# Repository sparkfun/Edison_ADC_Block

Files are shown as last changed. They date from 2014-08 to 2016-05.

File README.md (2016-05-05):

SparkFun Block for Intel Edison - ADC
==================================================

SparkFun Block for Intel Edison - ADC

[*SparkFun Block for Intel Edison - ADC (DEV-13770)*](https://www.sparkfun.com/products/13770)

This card adds ADC functionality to the Edison's I<sup>2</sup>C bus. 
The ADS1015 ADC from TI provides a single 12-bit delta-sigma convertor with an analog multiplexer. 
It can be configured as a four-channel single-ended device or as a two-channel differential device.

The board has jumpers to allow selection of the I<sup>2</sup>C slave address among four different options, allowing up to four of these cards to be stacked under one Edison. 
The sampling rate is not sufficient for audio capture, at 2.2kHz, but it should be adequate for most control applications.

Repository Contents
-------------------

* **/Hardware** - Eagle design files (.brd, .sch)
* **/Production** - Production panel files (.brd)

Documentation
--------------

* **[Hookup Guide](https://learn.sparkfun.com/tutorials/sparkfun-blocks-for-intel-edison---adc-v20)** - Basic hookup guide for the Edison ADC Block.
* **[SparkFun Fritzing repo](https://github.com/sparkfun/Fritzing_Parts)** - Fritzing diagrams for SparkFun products.
* **[SparkFun 3D Model repo](https://github.com/sparkfun/3D_Models)** - 3D models of SparkFun products. 

Version History
---------------
* [v21](https://github.com/sparkfun/Edison_ADC_Block/tree/V_2.1) - Version 2.1. Currently for sale. Fixes noise on the ADC lines, adds locking header footprint. 
* [v20](https://github.com/sparkfun/Edison_ADC_Block/tree/V_2.0) - Version 2.0. Retired. 
* [v10](https://github.com/sparkfun/Edison_ADC_Block/tree/v10) - Original release. Retired.

License Information
-------------------

This product is _**open source**_! 

Please review the LICENSE.md file for license information. 

If you have any questions or concerns on licensing, please contact techsupport@sparkfun.com.

Distributed as-is; no warranty is given.

- Your friends at SparkFun.

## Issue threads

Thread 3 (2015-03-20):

Flag label needed

ericorosel, 2015-03-20:
I think it would be nice to add a flag label to the VREF net connected to the 8-pin header, purely for the ease of reading/interpretation.

Right now it does not have any visible label.

caseykuhns, 2015-03-23:
fixed

Closed 2015-03-23.

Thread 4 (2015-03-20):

Board dimension thickness

ericorosel, 2015-03-20:
Noticed that the board dimension thickness is 6mil instead of 8mil.

If this is intentional disregard.

caseykuhns, 2015-03-23:
fixed

Closed 2015-03-23.

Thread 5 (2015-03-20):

Copper Pour Isolate

ericorosel, 2015-03-20:
Currently set to 2mil instead of 12mil.

if this is intentional, disregard.

caseykuhns, 2015-03-23:
fixed

ericorosel, 2015-03-24:
Looks like the isolate got set to 1.2mil instead of 12mil

caseykuhns, 2015-04-09:
Ok, I looked at other blocks and it looks like 2mil isolate is the norm.  We have 6mill spacing set by the DRU.  The 2mil allows the GND to connect to the edison connectors, without it, it gets ugly fast.

ericorosel, 2015-04-10:
Sounds good, thanks

Closed 2015-04-10.

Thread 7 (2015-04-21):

ADC Block V20 Proto Checklist #2 Issues

ericorosel, 2015-04-21:
(1) Looks like there is a mix and match of different sized traces around the PCA (some .01" and some .006"). The .006" traces going to the Hirose are okay, but I think we could go up to .01" on some of the smaller traces that do not lead to the Hirose.

As of now I think functionality should be fine, but for consistency, it may be worth changing some of the trace sizes; up to you.

(2) Can you add a line/polygon of "Trestrict" to the side of the GND pad on the PCA to get rid of the GND hash mark on the side of the pad. (Between SDA1 and GND)

(3) The measurement graphics are on "TDocu" instead of the "Measures" layer; up to you.

caseykuhns, 2015-04-26:
1) I fixed all trace widths to be .01" the .06 are connecting the hirose connectors
2) added the T restrict
3) Moved dimensions to Measures layer.

Closed 2015-04-26.

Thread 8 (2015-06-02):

Check the silk I added

mhord, 2015-06-02:
I removed the per-pin silk and added a table with the pertinent differential pin information. Check it and see if it matches expectations.

mhord, 2015-06-02:
Note that I didn't put it on both sides, however, so if editing it, please put a copy on the back once you're done!

Closed 2016-07-19.

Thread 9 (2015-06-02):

Regulator stability

mhord, 2015-06-02:
The 3.3V reference rail is bouncing all over the place, the same thing we saw with the FreeSoC2.

I tried a 2.2uF cap on there, as we've got on the FreeSoC, but no luck.

Probably going to have to find a higher ESR small package tant for this. Also, going to need another proto round to verify it.

Closed 2016-07-19.

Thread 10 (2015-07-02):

V20 Checklist Issues

ericorosel, 2015-07-02:
Got an air wire on the HIROSE connectors (top and bottom), looks like the GND pour doesn't want to make a connection. Upper right of the connector

caseykuhns, 2015-07-20:
should be good now, take a look

Closed 2015-07-20.

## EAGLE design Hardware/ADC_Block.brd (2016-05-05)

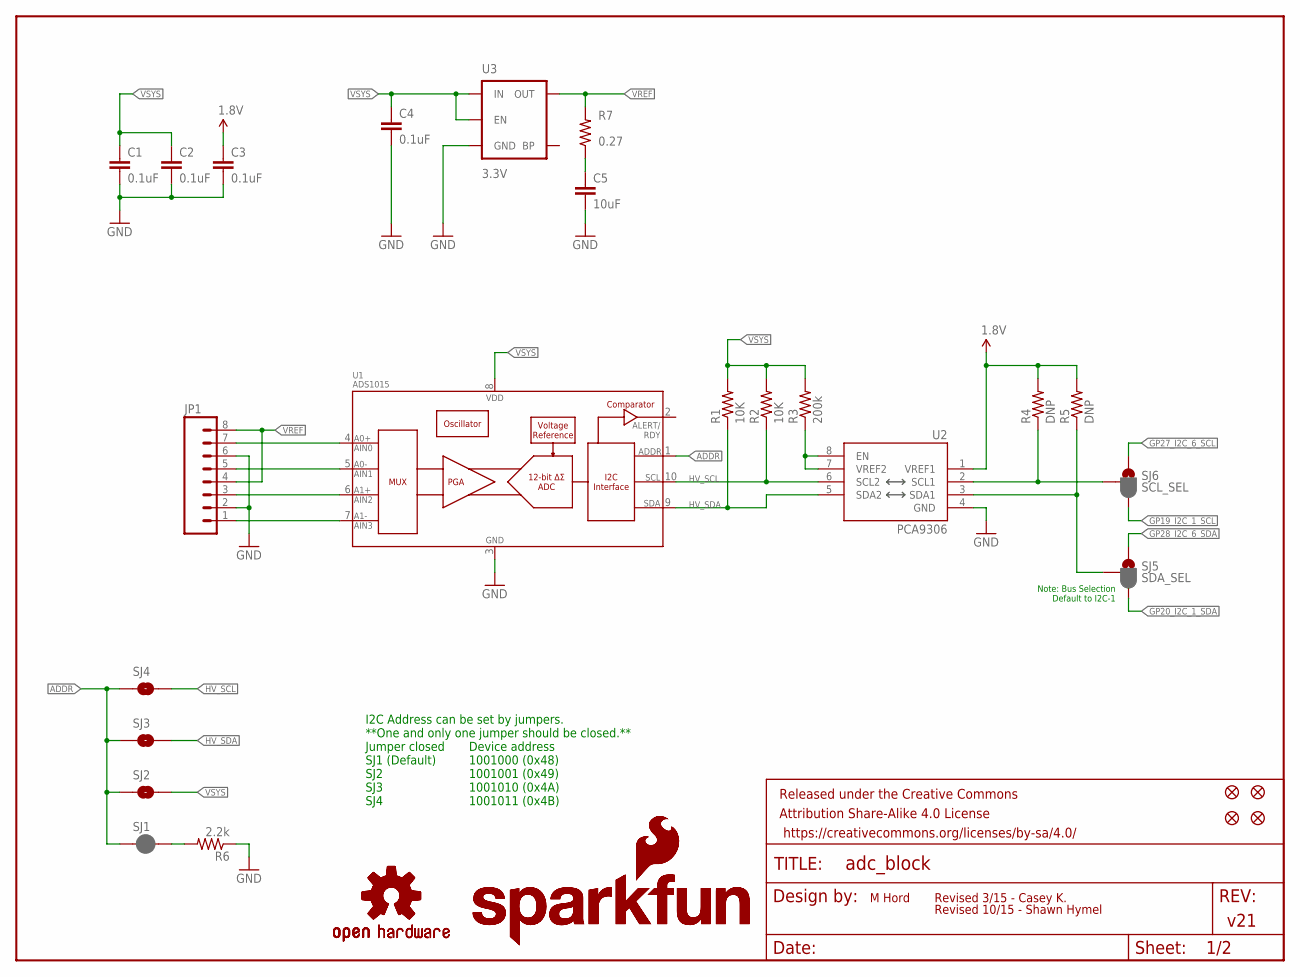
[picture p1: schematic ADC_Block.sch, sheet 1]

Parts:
C1, C2, C3, C4: 0.1uF; 0603-CAP
C5: 10uF; 0805-CAP
FID1, FID2, FID3, FID4: FIDUCIAL1X2; FIDUCIAL-1X2
FRAME1: FRAME-LETTER; CREATIVE_COMMONS
JP1: M08LOCK; 1X08_LOCK
LOGO1, LOGO3: SFE_LOGO_NAME_FLAME.1_INCH; SFE_LOGO_NAME_FLAME_.1
LOGO2, LOGO4: OSHW-LOGOS; OSHW-LOGO-S
R1, R2: 10K; 0603-RES
R3: 200k; 0603-RES
R4, R5: DNP; 0603-RES
R6: 2.2k; 0603-RES
R7: 0.27; 0603-RES
SJ1: JUMPER-PAD-2-NC_BY_PASTE; PAD-JUMPER-2-NC_BY_PASTE_YES_SILK
SJ2, SJ3, SJ4: JUMPER-PAD-2-NOYES_SILK; PAD-JUMPER-2-NO_YES_SILK
SJ5: SDA_SEL; PAD-JUMPER-3-2OF3_NC_BY_PASTE_YES_SILK_FULL_BOX
SJ6: SCL_SEL; PAD-JUMPER-3-2OF3_NC_BY_PASTE_YES_SILK_FULL_BOX
U1: ADS1015; MSOP10
U2: PCA9306; PCA9306DC-1:1
U3: 3.3V; SOT23-5

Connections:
1.8V: C3.1, R4.2, R5.2, U2.1 (VREF1); also elsewhere on the board
A0+/AIN0: JP1.7, U1.4 (AIN0)
A0-/AIN1: JP1.5, U1.5 (AIN1)
A1+/AIN2: JP1.3, U1.6 (AIN2)
A1-/AIN3: JP1.1, U1.7 (AIN3)
ADDR: SJ1.1, SJ2.1, SJ3.1, SJ4.1, U1.1 (ADDR)
GND: C1.2, C2.2, C3.2, C4.2, C5.2, JP1.2, JP1.6, R6.1, U1.3 (VSS), U2.4 (GND), U3.2 (GND); also elsewhere on the board
GP19_I2C_1_SCL: SJ6.3; also elsewhere on the board
GP20_I2C_1_SDA: SJ5.3; also elsewhere on the board
GP27_I2C_6_SCL: SJ6.1; also elsewhere on the board
GP28_I2C_6_SDA: SJ5.1; also elsewhere on the board
HV_SCL: R2.1, SJ4.2, U1.10 (SCL), U2.6 (SCL2)
HV_SDA: R1.1, SJ3.2, U1.9 (SDA), U2.5 (SDA2)
unnamed: R3.1, U2.7 (VREF2), U2.8 (EN)
unnamed: R4.1, SJ6.2, U2.2 (SCL1)
unnamed: R6.2, SJ1.2
unnamed: R5.1, SJ5.2, U2.3 (SDA1)
unnamed: C5.1, R7.1
VREF: JP1.4, JP1.8, R7.2, U3.5 (OUT)
VSYS: C1.1, C2.1, C4.1, R1.2, R2.2, R3.2, SJ2.2, U1.8 (VDD), U3.1 (IN), U3.3 (EN); also elsewhere on the board

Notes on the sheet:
I2C Address can be set by jumpers. **One and only one jumper should be closed.** Jumper closed SJ1 (Default) SJ2 SJ3 SJ4
Device address 1001000 (0x48) 1001001 (0x49) 1001010 (0x4A) 1001011 (0x4B)
v21
M Hord
Revised 3/15 - Casey K.
Note: Bus Selection Default to I2C-1
Revised 10/15 - Shawn Hymel

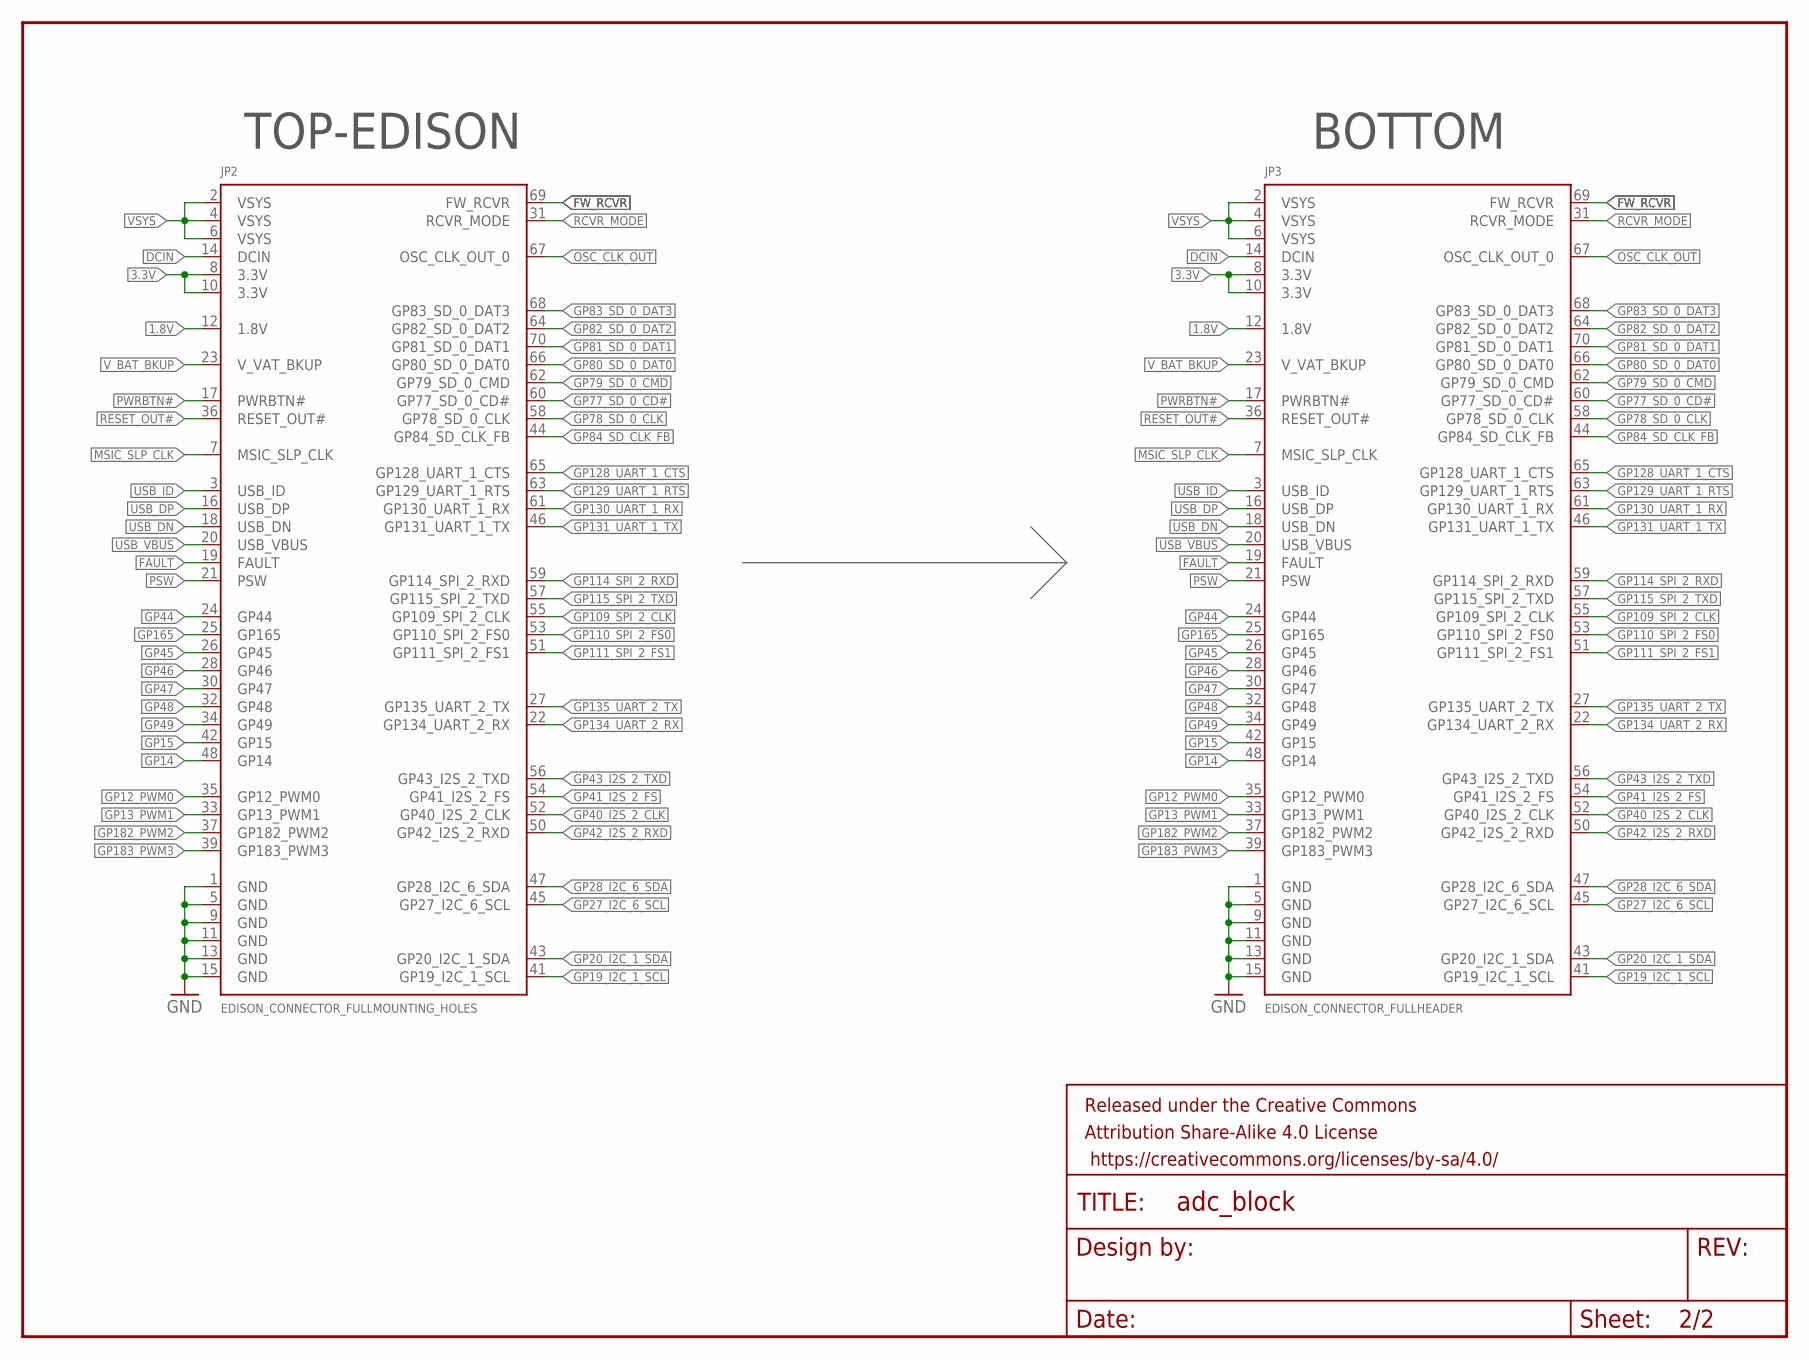
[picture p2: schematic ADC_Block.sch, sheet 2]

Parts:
FRAME2: FRAME-LETTER; CREATIVE_COMMONS
JP2: EDISON_CONNECTOR_FULLMOUNTING_HOLES; EDISON_DAUGHTER
JP3: EDISON_CONNECTOR_FULLHEADER; DF40C-70DP-0.4(51)

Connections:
1.8V: JP2.12 (1.8V), JP3.12 (1.8V); also elsewhere on the board
3.3V: JP2.8 (3.3V), JP2.10 (3.3V), JP3.8 (3.3V), JP3.10 (3.3V)
DCIN: JP2.14 (DCIN), JP3.14 (DCIN)
FAULT: JP2.19 (FAULT), JP3.19 (FAULT)
FW_RCVR: JP2.69 (FW_RCVR), JP3.69 (FW_RCVR)
GND: JP2.1 (GND), JP2.5 (GND), JP2.9 (GND), JP2.11 (GND), JP2.13 (GND), JP2.15 (GND), JP3.1 (GND), JP3.5 (GND), JP3.9 (GND), JP3.11 (GND), JP3.13 (GND), JP3.15 (GND); also elsewhere on the board
GP12_PWM0: JP2.35 (GP12_PWM0), JP3.35 (GP12_PWM0)
GP13_PWM1: JP2.33 (GP13_PWM1), JP3.33 (GP13_PWM1)
GP14: JP2.48 (GP14), JP3.48 (GP14)
GP15: JP2.42 (GP15), JP3.42 (GP15)
GP19_I2C_1_SCL: JP2.41 (GP19_I2C_1_SCL), JP3.41 (GP19_I2C_1_SCL); also elsewhere on the board
GP20_I2C_1_SDA: JP2.43 (GP20_I2C_1_SDA), JP3.43 (GP20_I2C_1_SDA); also elsewhere on the board
GP27_I2C_6_SCL: JP2.45 (GP27_I2C_6_SCL), JP3.45 (GP27_I2C_6_SCL); also elsewhere on the board
GP28_I2C_6_SDA: JP2.47 (GP28_I2C_6_SDA), JP3.47 (GP28_I2C_6_SDA); also elsewhere on the board
GP40_I2S_2_CLK: JP2.52 (GP40_I2S_2_CLK), JP3.52 (GP40_I2S_2_CLK)
GP41_I2S_2_FS: JP2.54 (GP41_I2S_2_FS), JP3.54 (GP41_I2S_2_FS)
GP42_I2S_2_RXD: JP2.50 (GP42_I2S_2_RXD), JP3.50 (GP42_I2S_2_RXD)
GP43_I2S_2_TXD: JP2.56 (GP43_I2S_2_TXD), JP3.56 (GP43_I2S_2_TXD)
GP44: JP2.24 (GP44), JP3.24 (GP44)
GP45: JP2.26 (GP45), JP3.26 (GP45)
GP46: JP2.28 (GP46), JP3.28 (GP46)
GP47: JP2.30 (GP47), JP3.30 (GP47)
GP48: JP2.32 (GP48), JP3.32 (GP48)
GP49: JP2.34 (GP49), JP3.34 (GP49)
GP77_SD_0_CD#: JP2.60 (GP77_SD_0_CD#), JP3.60 (GP77_SD_0_CD#)
GP78_SD_0_CLK: JP2.58 (GP78_SD_0_CLK), JP3.58 (GP78_SD_0_CLK)
GP79_SD_0_CMD: JP2.62 (GP79_SD_0_CMD), JP3.62 (GP79_SD_0_CMD)
GP80_SD_0_DAT0: JP2.66 (GP80_SD_0_DAT0), JP3.66 (GP80_SD_0_DAT0)
GP81_SD_0_DAT1: JP2.70 (GP81_SD_0_DAT1), JP3.70 (GP81_SD_0_DAT1)
GP82_SD_0_DAT2: JP2.64 (GP82_SD_0_DAT2), JP3.64 (GP82_SD_0_DAT2)
GP83_SD_0_DAT3: JP2.68 (GP83_SD_0_DAT3), JP3.68 (GP83_SD_0_DAT3)
GP84_SD_CLK_FB: JP2.44 (GP84_SD_CLK_FB), JP3.44 (GP84_SD_CLK_FB)
GP109_SPI_2_CLK: JP2.55 (GP109_SPI_2_CLK), JP3.55 (GP109_SPI_2_CLK)
GP110_SPI_2_FS0: JP2.53 (GP110_SPI_2_FS0), JP3.53 (GP110_SPI_2_FS0)
GP111_SPI_2_FS1: JP2.51 (GP111_SPI_2_FS1), JP3.51 (GP111_SPI_2_FS1)
GP114_SPI_2_RXD: JP2.59 (GP114_SPI_2_RXD), JP3.59 (GP114_SPI_2_RXD)
GP115_SPI_2_TXD: JP2.57 (GP115_SPI_2_TXD), JP3.57 (GP115_SPI_2_TXD)
GP128_UART_1_CTS: JP2.65 (GP128_UART_1_CTS), JP3.65 (GP128_UART_1_CTS)
GP129_UART_1_RTS: JP2.63 (GP129_UART_1_RTS), JP3.63 (GP129_UART_1_RTS)
GP130_UART_1_RX: JP2.61 (GP130_UART_1_RX), JP3.61 (GP130_UART_1_RX)
GP131_UART_1_TX: JP2.46 (GP131_UART_1_TX), JP3.46 (GP131_UART_1_TX)
GP134_UART_2_RX: JP2.22 (GP134_UART_2_RX), JP3.22 (GP134_UART_2_RX)
GP135_UART_2_TX: JP2.27 (GP135_UART_2_TX), JP3.27 (GP135_UART_2_TX)
GP165: JP2.25 (GP165), JP3.25 (GP165)
GP182_PWM2: JP2.37 (GP182_PWM2), JP3.37 (GP182_PWM2)
GP183_PWM3: JP2.39 (GP183_PWM3), JP3.39 (GP183_PWM3)
MSIC_SLP_CLK: JP2.7 (MSIC_SLP_CLK), JP3.7 (MSIC_SLP_CLK)
OSC_CLK_OUT: JP2.67 (OSC_CLK_OUT_0), JP3.67 (OSC_CLK_OUT_0)
PSW: JP2.21 (PSW), JP3.21 (PSW)
PWRBTN#: JP2.17 (PWRBTN#), JP3.17 (PWRBTN#)
RCVR_MODE: JP2.31 (RCVR_MODE), JP3.31 (RCVR_MODE)
RESET_OUT#: JP2.36 (RESET_OUT#), JP3.36 (RESET_OUT#)
USB_DN: JP2.18 (USB_DN), JP3.18 (USB_DN)
USB_DP: JP2.16 (USB_DP), JP3.16 (USB_DP)
USB_ID: JP2.3 (USB_ID), JP3.3 (USB_ID)
USB_VBUS: JP2.20 (USB_VBUS), JP3.20 (USB_VBUS)
VSYS: JP2.2 (VSYS), JP2.4 (VSYS), JP2.6 (VSYS), JP3.2 (VSYS), JP3.4 (VSYS), JP3.6 (VSYS); also elsewhere on the board
V_BAT_BKUP: JP2.23 (V_VAT_BKUP), JP3.23 (V_VAT_BKUP)

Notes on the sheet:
TOP-EDISON
BOTTOM

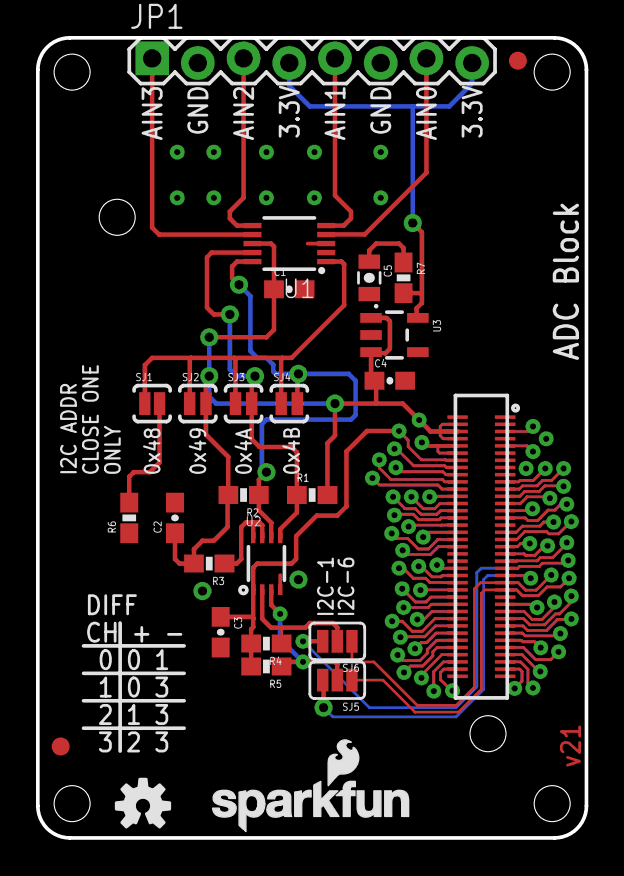
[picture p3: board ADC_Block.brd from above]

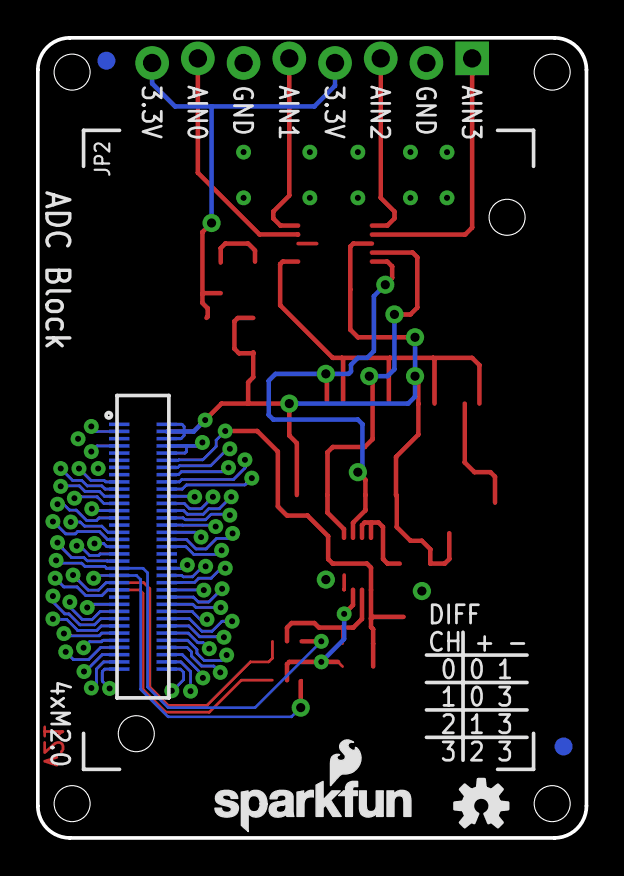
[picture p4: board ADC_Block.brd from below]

Board: 2 copper layers, 30.5 x 44.5 mm, 34 parts (6 on the bottom side), 71 nets.

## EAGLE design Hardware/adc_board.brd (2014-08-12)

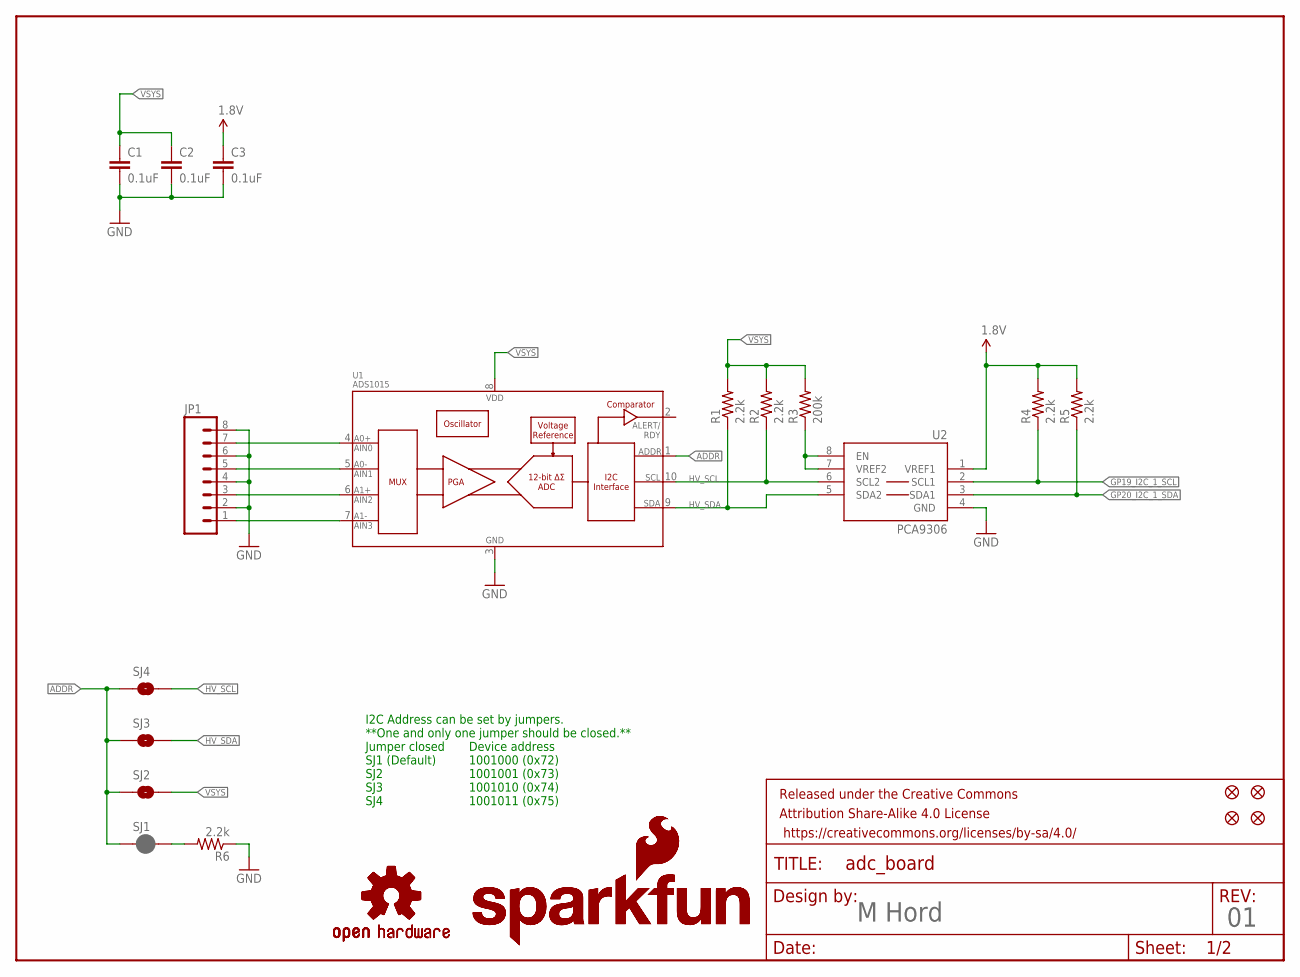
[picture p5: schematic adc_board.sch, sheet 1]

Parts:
C1, C2, C3: 0.1uF; 0603-CAP
FID1, FID2, FID3, FID4: FIDUCIAL1X2; FIDUCIAL-1X2
FRAME1: FRAME-LETTER; CREATIVE_COMMONS
JP1: M081X08; 1X08
LOGO1, LOGO3: SFE_LOGO_NAME_FLAME.1_INCH; SFE_LOGO_NAME_FLAME_.1
LOGO2, LOGO4: OSHW-LOGOS; OSHW-LOGO-S
R1, R2, R4, R5, R6: 2.2k; 0603-RES
R3: 200k; 0603-RES
SJ1: JUMPER-PAD-2-NC_BY_PASTE; PAD-JUMPER-2-NC_BY_PASTE_YES_SILK
SJ2, SJ3, SJ4: JUMPER-PAD-2-NOYES_SILK; PAD-JUMPER-2-NO_YES_SILK
U1: ADS1015; MSOP10
U2: PCA9306; PCA9306DC-1:1

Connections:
1.8V: C3.1, R4.2, R5.2, U2.1 (VREF1); also elsewhere on the board
A0+/AIN0: JP1.7, U1.4 (AIN0)
A0-/AIN1: JP1.5, U1.5 (AIN1)
A1+/AIN2: JP1.3, U1.6 (AIN2)
A1-/AIN3: JP1.1, U1.7 (AIN3)
ADDR: SJ1.1, SJ2.1, SJ3.1, SJ4.1, U1.1 (ADDR)
GND: C1.2, C2.2, C3.2, JP1.2, JP1.4, JP1.6, JP1.8, R6.1, U1.3 (VSS), U2.4 (GND); also elsewhere on the board
GP19_I2C_1_SCL: R4.1, U2.2 (SCL1); also elsewhere on the board
GP20_I2C_1_SDA: R5.1, U2.3 (SDA1); also elsewhere on the board
HV_SCL: R2.1, SJ4.2, U1.10 (SCL), U2.6 (SCL2)
HV_SDA: R1.1, SJ3.2, U1.9 (SDA), U2.5 (SDA2)
unnamed: R3.1, U2.7 (VREF2), U2.8 (EN)
unnamed: R6.2, SJ1.2
VSYS: C1.1, C2.1, R1.2, R2.2, R3.2, SJ2.2, U1.8 (VDD); also elsewhere on the board

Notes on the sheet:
I2C Address can be set by jumpers. **One and only one jumper should be closed.** Jumper closed SJ1 (Default) SJ2 SJ3 SJ4
Device address 1001000 (0x72) 1001001 (0x73) 1001010 (0x74) 1001011 (0x75)
M Hord

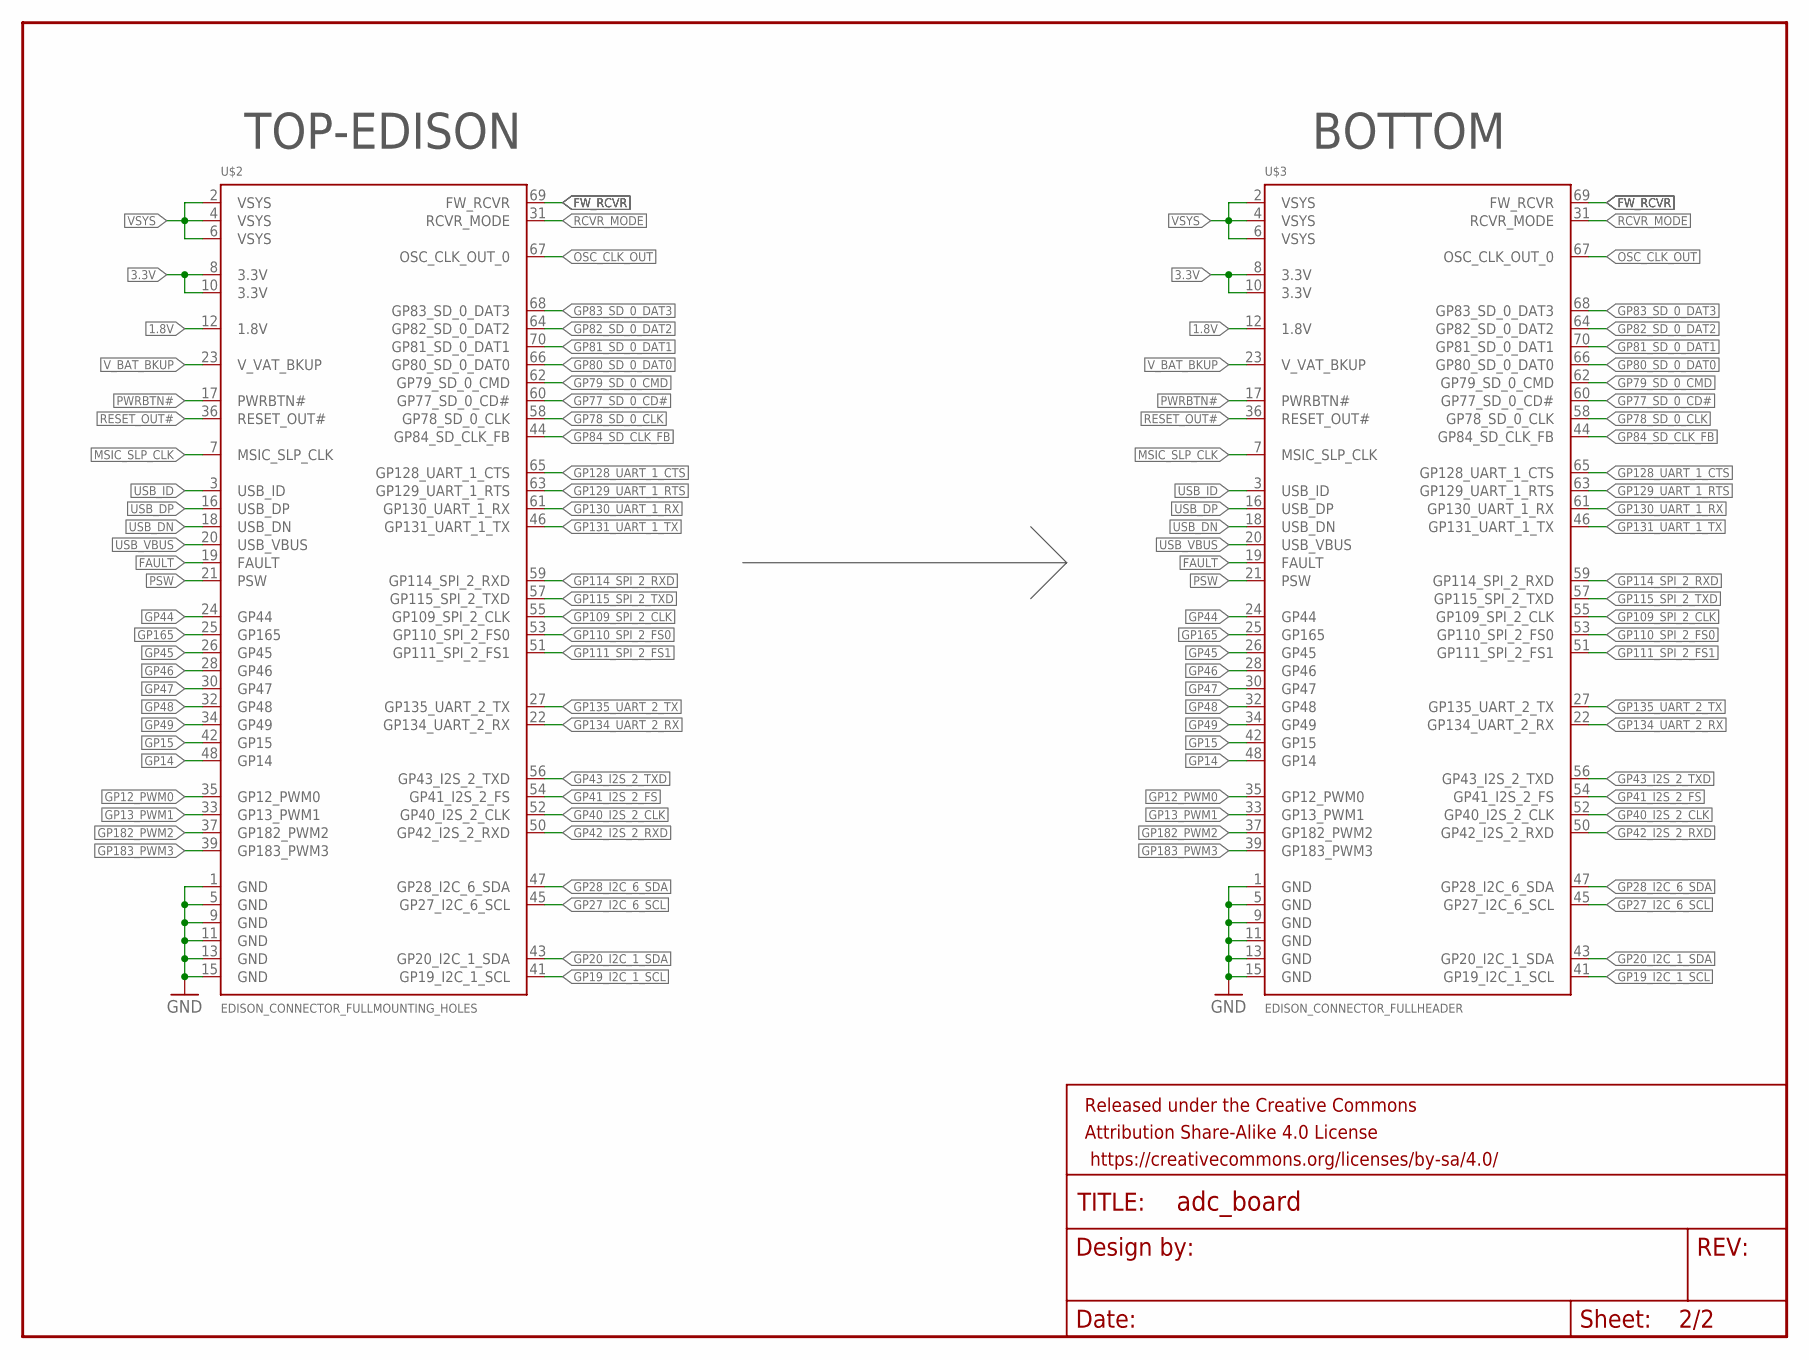
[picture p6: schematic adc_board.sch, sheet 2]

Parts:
FRAME2: FRAME-LETTER; CREATIVE_COMMONS
U$2: EDISON_CONNECTOR_FULLMOUNTING_HOLES; EDISON_DAUGHTER
U$3: EDISON_CONNECTOR_FULLHEADER; DF40C-70DP-0.4(51)

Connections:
1.8V: U$2.12 (1.8V), U$3.12 (1.8V); also elsewhere on the board
3.3V: U$2.8 (3.3V), U$2.10 (3.3V), U$3.8 (3.3V), U$3.10 (3.3V)
FAULT: U$2.19 (FAULT), U$3.19 (FAULT)
FW_RCVR: U$2.69 (FW_RCVR), U$3.69 (FW_RCVR)
GND: U$2.1 (GND), U$2.5 (GND), U$2.9 (GND), U$2.11 (GND), U$2.13 (GND), U$2.15 (GND), U$3.1 (GND), U$3.5 (GND), U$3.9 (GND), U$3.11 (GND), U$3.13 (GND), U$3.15 (GND); also elsewhere on the board
GP12_PWM0: U$2.35 (GP12_PWM0), U$3.35 (GP12_PWM0)
GP13_PWM1: U$2.33 (GP13_PWM1), U$3.33 (GP13_PWM1)
GP14: U$2.48 (GP14), U$3.48 (GP14)
GP15: U$2.42 (GP15), U$3.42 (GP15)
GP19_I2C_1_SCL: U$2.41 (GP19_I2C_1_SCL), U$3.41 (GP19_I2C_1_SCL); also elsewhere on the board
GP20_I2C_1_SDA: U$2.43 (GP20_I2C_1_SDA), U$3.43 (GP20_I2C_1_SDA); also elsewhere on the board
GP27_I2C_6_SCL: U$2.45 (GP27_I2C_6_SCL), U$3.45 (GP27_I2C_6_SCL)
GP28_I2C_6_SDA: U$2.47 (GP28_I2C_6_SDA), U$3.47 (GP28_I2C_6_SDA)
GP40_I2S_2_CLK: U$2.52 (GP40_I2S_2_CLK), U$3.52 (GP40_I2S_2_CLK)
GP41_I2S_2_FS: U$2.54 (GP41_I2S_2_FS), U$3.54 (GP41_I2S_2_FS)
GP42_I2S_2_RXD: U$2.50 (GP42_I2S_2_RXD), U$3.50 (GP42_I2S_2_RXD)
GP43_I2S_2_TXD: U$2.56 (GP43_I2S_2_TXD), U$3.56 (GP43_I2S_2_TXD)
GP44: U$2.24 (GP44), U$3.24 (GP44)
GP45: U$2.26 (GP45), U$3.26 (GP45)
GP46: U$2.28 (GP46), U$3.28 (GP46)
GP47: U$2.30 (GP47), U$3.30 (GP47)
GP48: U$2.32 (GP48), U$3.32 (GP48)
GP49: U$2.34 (GP49), U$3.34 (GP49)
GP77_SD_0_CD#: U$2.60 (GP77_SD_0_CD#), U$3.60 (GP77_SD_0_CD#)
GP78_SD_0_CLK: U$2.58 (GP78_SD_0_CLK), U$3.58 (GP78_SD_0_CLK)
GP79_SD_0_CMD: U$2.62 (GP79_SD_0_CMD), U$3.62 (GP79_SD_0_CMD)
GP80_SD_0_DAT0: U$2.66 (GP80_SD_0_DAT0), U$3.66 (GP80_SD_0_DAT0)
GP81_SD_0_DAT1: U$2.70 (GP81_SD_0_DAT1), U$3.70 (GP81_SD_0_DAT1)
GP82_SD_0_DAT2: U$2.64 (GP82_SD_0_DAT2), U$3.64 (GP82_SD_0_DAT2)
GP83_SD_0_DAT3: U$2.68 (GP83_SD_0_DAT3), U$3.68 (GP83_SD_0_DAT3)
GP84_SD_CLK_FB: U$2.44 (GP84_SD_CLK_FB), U$3.44 (GP84_SD_CLK_FB)
GP109_SPI_2_CLK: U$2.55 (GP109_SPI_2_CLK), U$3.55 (GP109_SPI_2_CLK)
GP110_SPI_2_FS0: U$2.53 (GP110_SPI_2_FS0), U$3.53 (GP110_SPI_2_FS0)
GP111_SPI_2_FS1: U$2.51 (GP111_SPI_2_FS1), U$3.51 (GP111_SPI_2_FS1)
GP114_SPI_2_RXD: U$2.59 (GP114_SPI_2_RXD), U$3.59 (GP114_SPI_2_RXD)
GP115_SPI_2_TXD: U$2.57 (GP115_SPI_2_TXD), U$3.57 (GP115_SPI_2_TXD)
GP128_UART_1_CTS: U$2.65 (GP128_UART_1_CTS), U$3.65 (GP128_UART_1_CTS)
GP129_UART_1_RTS: U$2.63 (GP129_UART_1_RTS), U$3.63 (GP129_UART_1_RTS)
GP130_UART_1_RX: U$2.61 (GP130_UART_1_RX), U$3.61 (GP130_UART_1_RX)
GP131_UART_1_TX: U$2.46 (GP131_UART_1_TX), U$3.46 (GP131_UART_1_TX)
GP134_UART_2_RX: U$2.22 (GP134_UART_2_RX), U$3.22 (GP134_UART_2_RX)
GP135_UART_2_TX: U$2.27 (GP135_UART_2_TX), U$3.27 (GP135_UART_2_TX)
GP165: U$2.25 (GP165), U$3.25 (GP165)
GP182_PWM2: U$2.37 (GP182_PWM2), U$3.37 (GP182_PWM2)
GP183_PWM3: U$2.39 (GP183_PWM3), U$3.39 (GP183_PWM3)
MSIC_SLP_CLK: U$2.7 (MSIC_SLP_CLK), U$3.7 (MSIC_SLP_CLK)
OSC_CLK_OUT: U$2.67 (OSC_CLK_OUT_0), U$3.67 (OSC_CLK_OUT_0)
PSW: U$2.21 (PSW), U$3.21 (PSW)
PWRBTN#: U$2.17 (PWRBTN#), U$3.17 (PWRBTN#)
RCVR_MODE: U$2.31 (RCVR_MODE), U$3.31 (RCVR_MODE)
RESET_OUT#: U$2.36 (RESET_OUT#), U$3.36 (RESET_OUT#)
USB_DN: U$2.18 (USB_DN), U$3.18 (USB_DN)
USB_DP: U$2.16 (USB_DP), U$3.16 (USB_DP)
USB_ID: U$2.3 (USB_ID), U$3.3 (USB_ID)
USB_VBUS: U$2.20 (USB_VBUS), U$3.20 (USB_VBUS)
VSYS: U$2.2 (VSYS), U$2.4 (VSYS), U$2.6 (VSYS), U$3.2 (VSYS), U$3.4 (VSYS), U$3.6 (VSYS); also elsewhere on the board
V_BAT_BKUP: U$2.23 (V_VAT_BKUP), U$3.23 (V_VAT_BKUP)

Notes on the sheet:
TOP-EDISON
BOTTOM

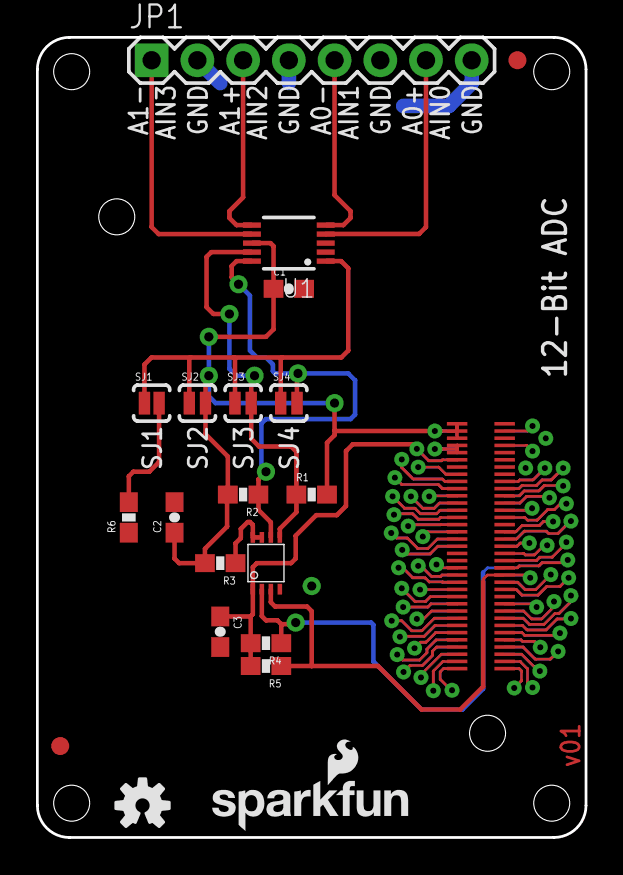
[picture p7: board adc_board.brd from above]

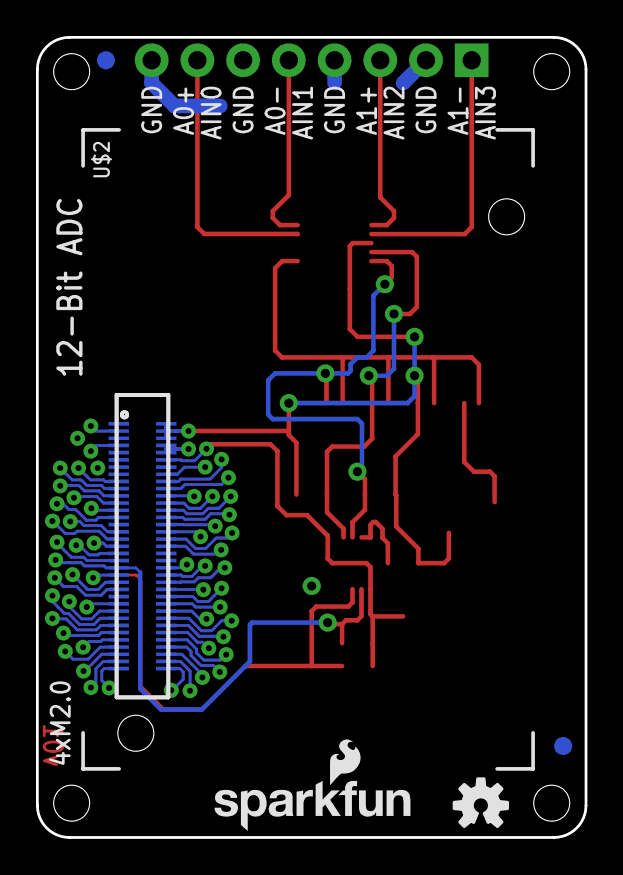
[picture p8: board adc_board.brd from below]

Board: 2 copper layers, 30.5 x 44.5 mm, 28 parts (6 on the bottom side), 66 nets.

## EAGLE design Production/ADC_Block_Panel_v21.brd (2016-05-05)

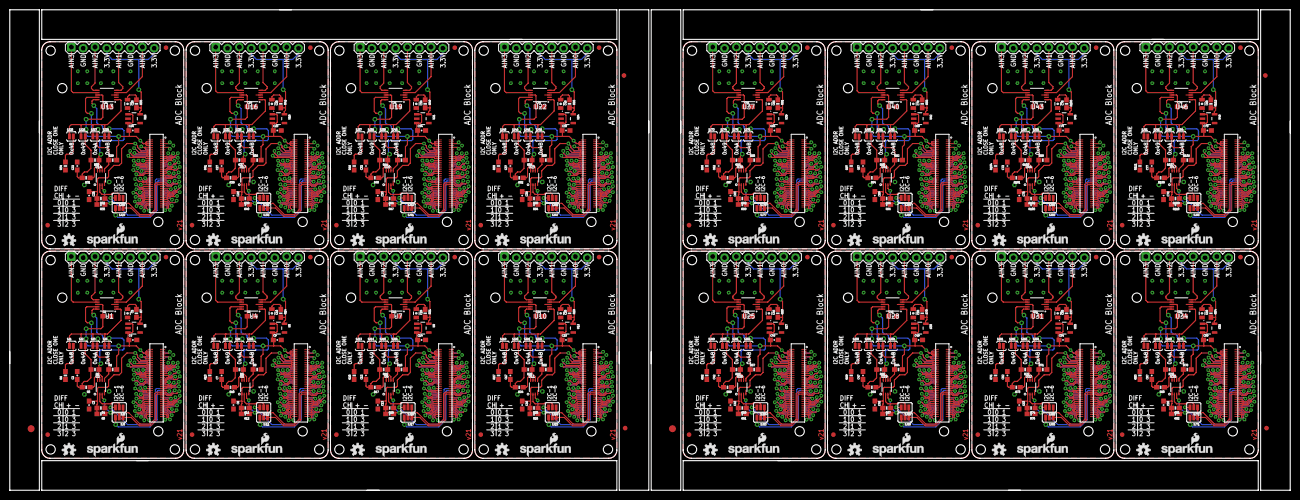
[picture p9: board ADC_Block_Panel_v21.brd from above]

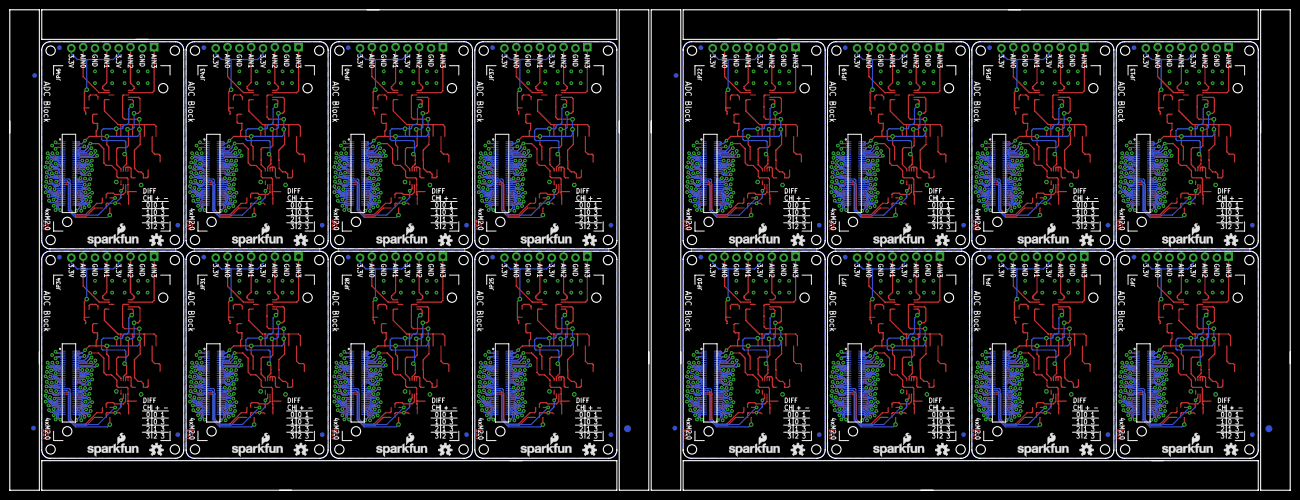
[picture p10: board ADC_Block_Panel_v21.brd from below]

Board: 2 copper layers, 274.8 x 103.1 mm, 524 parts (102 on the bottom side), 1136 nets.

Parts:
C1, C2, C3, C4, C6, C7, C8, C9, C11, C12, C13, C14, C16, C17, C18, C19, C21, C22, C23, C24, C26, C27, C28, C29, C31, C32, C33, C34, C36, C37, C38, C39, C41, C42, C43, C44, C46, C47, C48, C49, C51, C52, C53, C54, C56, C57, C58, C59, C61, C62, C63, C64, C66, C67, C68, C69, C71, C72, C73, C74, C76, C77, C78, C79: 0.1uF; 0603-CAP
C5, C10, C15, C20, C25, C30, C35, C40, C45, C50, C55, C60, C65, C70, C75, C80: 10uF; 0805-CAP
E$1, E$4, E$5, E$9: FIDUCIAL-1.5X3
E$2, E$3, E$6, E$7, E$8, E$10, E$11, E$12: FIDUCIAL-1X2
FID1, FID2, FID3, FID4, FID5, FID6, FID7, FID8, FID9, FID10, FID11, FID12, FID13, FID14, FID15, FID16, FID17, FID18, FID19, FID20, FID21, FID22, FID23, FID24, FID25, FID26, FID27, FID28, FID29, FID30, FID31, FID32, FID33, FID34, FID35, FID36, FID37, FID38, FID39, FID40, FID41, FID42, FID43, FID44, FID45, FID46, FID47, FID48, FID49, FID50, FID51, FID52, FID53, FID54, FID55, FID56, FID57, FID58, FID59, FID60, FID61, FID62, FID63, FID64: FIDUCIAL1X2; FIDUCIAL-1X2
JP1, JP6, JP9, JP12, JP15, JP18, JP21, JP24, JP27, JP30, JP33, JP36, JP39, JP42, JP45, JP48: 1X08_LOCK
JP2, JP4, JP7, JP10, JP13, JP16, JP19, JP22, JP25, JP28, JP31, JP34, JP37, JP40, JP43, JP46: EDISON_CONNECTOR_FULLMOUNTING_HOLES; EDISON_DAUGHTER
JP3, JP5, JP8, JP11, JP14, JP17, JP20, JP23, JP26, JP29, JP32, JP35, JP38, JP41, JP44, JP47: EDISON_CONNECTOR_FULLHEADER; DF40C-70DP-0.4(51)
LOGO1, LOGO3, LOGO6, LOGO7, LOGO10, LOGO11, LOGO14, LOGO15, LOGO18, LOGO19, LOGO22, LOGO23, LOGO26, LOGO27, LOGO30, LOGO31, LOGO34, LOGO35, LOGO38, LOGO39, LOGO42, LOGO43, LOGO46, LOGO47, LOGO50, LOGO51, LOGO54, LOGO55, LOGO58, LOGO59, LOGO62, LOGO63: SFE_LOGO_NAME_FLAME.1_INCH; SFE_LOGO_NAME_FLAME_.1
LOGO2, LOGO4, LOGO5, LOGO8, LOGO9, LOGO12, LOGO13, LOGO16, LOGO17, LOGO20, LOGO21, LOGO24, LOGO25, LOGO28, LOGO29, LOGO32, LOGO33, LOGO36, LOGO37, LOGO40, LOGO41, LOGO44, LOGO45, LOGO48, LOGO49, LOGO52, LOGO53, LOGO56, LOGO57, LOGO60, LOGO61, LOGO64: OSHW-LOGOS; OSHW-LOGO-S
R1, R2, R8, R9, R15, R16, R22, R23, R29, R30, R36, R37, R43, R44, R50, R51, R57, R58, R64, R65, R71, R72, R78, R79, R85, R86, R92, R93, R99, R100, R106, R107: 10K; 0603-RES
R3, R10, R17, R24, R31, R38, R45, R52, R59, R66, R73, R80, R87, R94, R101, R108: 200k; 0603-RES
R4, R5, R11, R12, R18, R19, R25, R26, R32, R33, R39, R40, R46, R47, R53, R54, R60, R61, R67, R68, R74, R75, R81, R82, R88, R89, R95, R96, R102, R103, R109, R110: DNP; 0603-RES
R6, R13, R20, R27, R34, R41, R48, R55, R62, R69, R76, R83, R90, R97, R104, R111: 2.2k; 0603-RES
R7, R14, R21, R28, R35, R42, R49, R56, R63, R70, R77, R84, R91, R98, R105, R112: 0.27; 0603-RES
SJ1, SJ7, SJ13, SJ19, SJ25, SJ31, SJ37, SJ43, SJ49, SJ55, SJ61, SJ67, SJ73, SJ79, SJ85, SJ91: JUMPER-PAD-2-NC_BY_PASTE; PAD-JUMPER-2-NC_BY_PASTE_YES_SILK
SJ2, SJ3, SJ4, SJ8, SJ9, SJ10, SJ14, SJ15, SJ16, SJ20, SJ21, SJ22, SJ26, SJ27, SJ28, SJ32, SJ33, SJ34, SJ38, SJ39, SJ40, SJ44, SJ45, SJ46, SJ50, SJ51, SJ52, SJ56, SJ57, SJ58, SJ62, SJ63, SJ64, SJ68, SJ69, SJ70, SJ74, SJ75, SJ76, SJ80, SJ81, SJ82, SJ86, SJ87, SJ88, SJ92, SJ93, SJ94: JUMPER-PAD-2-NOYES_SILK; PAD-JUMPER-2-NO_YES_SILK
SJ5, SJ11, SJ17, SJ23, SJ29, SJ35, SJ41, SJ47, SJ53, SJ59, SJ65, SJ71, SJ77, SJ83, SJ89, SJ95: SDA_SEL; PAD-JUMPER-3-2OF3_NC_BY_PASTE_YES_SILK_FULL_BOX
SJ6, SJ12, SJ18, SJ24, SJ30, SJ36, SJ42, SJ48, SJ54, SJ60, SJ66, SJ72, SJ78, SJ84, SJ90, SJ96: SCL_SEL; PAD-JUMPER-3-2OF3_NC_BY_PASTE_YES_SILK_FULL_BOX
U1, U4, U7, U10, U13, U16, U19, U22, U25, U28, U31, U34, U37, U40, U43, U46: ADS1015; MSOP10
U2, U5, U8, U11, U14, U17, U20, U23, U26, U29, U32, U35, U38, U41, U44, U47: PCA9306; PCA9306DC-1:1
U3, U6, U9, U12, U15, U18, U21, U24, U27, U30, U33, U36, U39, U42, U45, U48: 3.3V; SOT23-5

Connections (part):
1.8V: C3.1, JP2.12, JP3.12, R4.2, R5.2, U2.1
1.8V1: C8.1, JP4.12, JP5.12, R11.2, R12.2, U5.1
1.8V2: C13.1, JP7.12, JP8.12, R18.2, R19.2, U8.1
1.8V3: C18.1, JP10.12, JP11.12, R25.2, R26.2, U11.1
1.8V4: C23.1, JP13.12, JP14.12, R32.2, R33.2, U14.1
1.8V5: C28.1, JP16.12, JP17.12, R39.2, R40.2, U17.1
1.8V6: C33.1, JP19.12, JP20.12, R46.2, R47.2, U20.1
1.8V7: C38.1, JP22.12, JP23.12, R53.2, R54.2, U23.1
1.8V8: C43.1, JP25.12, JP26.12, R60.2, R61.2, U26.1
1.8V9: C48.1, JP28.12, JP29.12, R67.2, R68.2, U29.1
1.8V10: C53.1, JP31.12, JP32.12, R74.2, R75.2, U32.1
1.8V11: C58.1, JP34.12, JP35.12, R81.2, R82.2, U35.1
1.8V12: C63.1, JP37.12, JP38.12, R88.2, R89.2, U38.1
1.8V13: C68.1, JP40.12, JP41.12, R95.2, R96.2, U41.1
1.8V14: C73.1, JP43.12, JP44.12, R102.2, R103.2, U44.1
1.8V15: C78.1, JP46.12, JP47.12, R109.2, R110.2, U47.1
3.3V: JP2.8, JP2.10, JP3.8, JP3.10
3.3V1: JP4.8, JP4.10, JP5.8, JP5.10
3.3V2: JP7.8, JP7.10, JP8.8, JP8.10
3.3V3: JP10.8, JP10.10, JP11.8, JP11.10
3.3V4: JP13.8, JP13.10, JP14.8, JP14.10
3.3V5: JP16.8, JP16.10, JP17.8, JP17.10
3.3V6: JP19.8, JP19.10, JP20.8, JP20.10
3.3V7: JP22.8, JP22.10, JP23.8, JP23.10
3.3V8: JP25.8, JP25.10, JP26.8, JP26.10
3.3V9: JP28.8, JP28.10, JP29.8, JP29.10
3.3V10: JP31.8, JP31.10, JP32.8, JP32.10
3.3V11: JP34.8, JP34.10, JP35.8, JP35.10
3.3V12: JP37.8, JP37.10, JP38.8, JP38.10
3.3V13: JP40.8, JP40.10, JP41.8, JP41.10
3.3V14: JP43.8, JP43.10, JP44.8, JP44.10
3.3V15: JP46.8, JP46.10, JP47.8, JP47.10
A0+/AIN0: JP1.7, U1.4
A0+/AIN1: JP6.7, U4.4
A0+/AIN2: JP9.7, U7.4
A0+/AIN3: JP12.7, U10.4
A0+/AIN4: JP15.7, U13.4
A0+/AIN5: JP18.7, U16.4
A0+/AIN6: JP21.7, U19.4
A0+/AIN7: JP24.7, U22.4
A0+/AIN8: JP27.7, U25.4
A0+/AIN9: JP30.7, U28.4
A0+/AIN10: JP33.7, U31.4
A0+/AIN11: JP36.7, U34.4
A0+/AIN12: JP39.7, U37.4
A0+/AIN13: JP42.7, U40.4
A0+/AIN14: JP45.7, U43.4
A0+/AIN15: JP48.7, U46.4
A0-/AIN1: JP1.5, U1.5
A0-/AIN2: JP6.5, U4.5
A0-/AIN3: JP9.5, U7.5
A0-/AIN4: JP12.5, U10.5
A0-/AIN5: JP15.5, U13.5
A0-/AIN6: JP18.5, U16.5
A0-/AIN7: JP21.5, U19.5
A0-/AIN8: JP24.5, U22.5
A0-/AIN9: JP27.5, U25.5
A0-/AIN10: JP30.5, U28.5
A0-/AIN11: JP33.5, U31.5
A0-/AIN12: JP36.5, U34.5
A0-/AIN13: JP39.5, U37.5
A0-/AIN14: JP42.5, U40.5
A0-/AIN15: JP45.5, U43.5
A0-/AIN16: JP48.5, U46.5
A1+/AIN1: JP6.3, U4.6
A1+/AIN2: JP1.3, U1.6
A1+/AIN3: JP9.3, U7.6
A1+/AIN4: JP12.3, U10.6
A1+/AIN5: JP15.3, U13.6
A1+/AIN6: JP18.3, U16.6
A1+/AIN7: JP21.3, U19.6
A1+/AIN8: JP24.3, U22.6
A1+/AIN9: JP27.3, U25.6
A1+/AIN10: JP30.3, U28.6
A1+/AIN11: JP33.3, U31.6
A1+/AIN12: JP36.3, U34.6
A1+/AIN13: JP39.3, U37.6
A1+/AIN14: JP42.3, U40.6
A1+/AIN15: JP45.3, U43.6
A1+/AIN16: JP48.3, U46.6
A1-/AIN1: JP6.1, U4.7
A1-/AIN2: JP9.1, U7.7
A1-/AIN3: JP1.1, U1.7
A1-/AIN4: JP12.1, U10.7
A1-/AIN5: JP15.1, U13.7
A1-/AIN6: JP18.1, U16.7
A1-/AIN7: JP21.1, U19.7
A1-/AIN8: JP24.1, U22.7
A1-/AIN9: JP27.1, U25.7
A1-/AIN10: JP30.1, U28.7
A1-/AIN11: JP33.1, U31.7
A1-/AIN12: JP36.1, U34.7
A1-/AIN13: JP39.1, U37.7
A1-/AIN14: JP42.1, U40.7
A1-/AIN15: JP45.1, U43.7
A1-/AIN16: JP48.1, U46.7
ADDR: SJ1.1, SJ2.1, SJ3.1, SJ4.1, U1.1
ADDR1: SJ7.1, SJ8.1, SJ9.1, SJ10.1, U4.1
ADDR2: SJ13.1, SJ14.1, SJ15.1, SJ16.1, U7.1
ADDR3: SJ19.1, SJ20.1, SJ21.1, SJ22.1, U10.1
ADDR4: SJ25.1, SJ26.1, SJ27.1, SJ28.1, U13.1
ADDR5: SJ31.1, SJ32.1, SJ33.1, SJ34.1, U16.1
ADDR6: SJ37.1, SJ38.1, SJ39.1, SJ40.1, U19.1
ADDR7: SJ43.1, SJ44.1, SJ45.1, SJ46.1, U22.1
ADDR8: SJ49.1, SJ50.1, SJ51.1, SJ52.1, U25.1
ADDR9: SJ55.1, SJ56.1, SJ57.1, SJ58.1, U28.1
ADDR10: SJ61.1, SJ62.1, SJ63.1, SJ64.1, U31.1
ADDR11: SJ67.1, SJ68.1, SJ69.1, SJ70.1, U34.1
ADDR12: SJ73.1, SJ74.1, SJ75.1, SJ76.1, U37.1
ADDR13: SJ79.1, SJ80.1, SJ81.1, SJ82.1, U40.1
ADDR14: SJ85.1, SJ86.1, SJ87.1, SJ88.1, U43.1
ADDR15: SJ91.1, SJ92.1, SJ93.1, SJ94.1, U46.1
DCIN: JP2.14, JP3.14
DCIN1: JP4.14, JP5.14
DCIN2: JP7.14, JP8.14
DCIN3: JP10.14, JP11.14
DCIN4: JP13.14, JP14.14
DCIN5: JP16.14, JP17.14
DCIN6: JP19.14, JP20.14
DCIN7: JP22.14, JP23.14
DCIN8: JP25.14, JP26.14
DCIN9: JP28.14, JP29.14
DCIN10: JP31.14, JP32.14
DCIN11: JP34.14, JP35.14
DCIN12: JP37.14, JP38.14
DCIN13: JP40.14, JP41.14
DCIN14: JP43.14, JP44.14
DCIN15: JP46.14, JP47.14
FAULT: JP2.19, JP3.19
FAULT1: JP4.19, JP5.19
FAULT2: JP7.19, JP8.19
FAULT3: JP10.19, JP11.19
FAULT4: JP13.19, JP14.19
FAULT5: JP16.19, JP17.19
FAULT6: JP19.19, JP20.19
FAULT7: JP22.19, JP23.19
FAULT8: JP25.19, JP26.19
FAULT9: JP28.19, JP29.19
FAULT10: JP31.19, JP32.19
FAULT11: JP34.19, JP35.19
FAULT12: JP37.19, JP38.19
FAULT13: JP40.19, JP41.19
FAULT14: JP43.19, JP44.19
FAULT15: JP46.19, JP47.19
FW_RCVR: JP2.69, JP3.69
FW_RCVR1: JP4.69, JP5.69
FW_RCVR2: JP7.69, JP8.69
FW_RCVR3: JP10.69, JP11.69
FW_RCVR4: JP13.69, JP14.69
FW_RCVR5: JP16.69, JP17.69
FW_RCVR6: JP19.69, JP20.69
FW_RCVR7: JP22.69, JP23.69
FW_RCVR8: JP25.69, JP26.69
FW_RCVR9: JP28.69, JP29.69
FW_RCVR10: JP31.69, JP32.69
FW_RCVR11: JP34.69, JP35.69
FW_RCVR12: JP37.69, JP38.69
FW_RCVR13: JP40.69, JP41.69
FW_RCVR14: JP43.69, JP44.69
FW_RCVR15: JP46.69, JP47.69
GND: C1.2, C2.2, C3.2, C4.2, C5.2, JP1.2, JP1.6, JP2.1, JP2.5, JP2.9, JP2.11, JP2.13, JP2.15, JP3.1, JP3.5, JP3.9, JP3.11, JP3.13, JP3.15, R6.1, U1.3, U2.4, U3.2
GND1: C6.2, C7.2, C8.2, C9.2, C10.2, JP4.1, JP4.5, JP4.9, JP4.11, JP4.13, JP4.15, JP5.1, JP5.5, JP5.9, JP5.11, JP5.13, JP5.15, JP6.2, JP6.6, R13.1, U4.3, U5.4, U6.2
GND2: C11.2, C12.2, C13.2, C14.2, C15.2, JP7.1, JP7.5, JP7.9, JP7.11, JP7.13, JP7.15, JP8.1, JP8.5, JP8.9, JP8.11, JP8.13, JP8.15, JP9.2, JP9.6, R20.1, U7.3, U8.4, U9.2
GND3: C16.2, C17.2, C18.2, C19.2, C20.2, JP10.1, JP10.5, JP10.9, JP10.11, JP10.13, JP10.15, JP11.1, JP11.5, JP11.9, JP11.11, JP11.13, JP11.15, JP12.2, JP12.6, R27.1, U10.3, U11.4, U12.2
GND4: C21.2, C22.2, C23.2, C24.2, C25.2, JP13.1, JP13.5, JP13.9, JP13.11, JP13.13, JP13.15, JP14.1, JP14.5, JP14.9, JP14.11, JP14.13, JP14.15, JP15.2, JP15.6, R34.1, U13.3, U14.4, U15.2
GND5: C26.2, C27.2, C28.2, C29.2, C30.2, JP16.1, JP16.5, JP16.9, JP16.11, JP16.13, JP16.15, JP17.1, JP17.5, JP17.9, JP17.11, JP17.13, JP17.15, JP18.2, JP18.6, R41.1, U16.3, U17.4, U18.2
GND6: C31.2, C32.2, C33.2, C34.2, C35.2, JP19.1, JP19.5, JP19.9, JP19.11, JP19.13, JP19.15, JP20.1, JP20.5, JP20.9, JP20.11, JP20.13, JP20.15, JP21.2, JP21.6, R48.1, U19.3, U20.4, U21.2
GND7: C36.2, C37.2, C38.2, C39.2, C40.2, JP22.1, JP22.5, JP22.9, JP22.11, JP22.13, JP22.15, JP23.1, JP23.5, JP23.9, JP23.11, JP23.13, JP23.15, JP24.2, JP24.6, R55.1, U22.3, U23.4, U24.2
GND8: C41.2, C42.2, C43.2, C44.2, C45.2, JP25.1, JP25.5, JP25.9, JP25.11, JP25.13, JP25.15, JP26.1, JP26.5, JP26.9, JP26.11, JP26.13, JP26.15, JP27.2, JP27.6, R62.1, U25.3, U26.4, U27.2
GND9: C46.2, C47.2, C48.2, C49.2, C50.2, JP28.1, JP28.5, JP28.9, JP28.11, JP28.13, JP28.15, JP29.1, JP29.5, JP29.9, JP29.11, JP29.13, JP29.15, JP30.2, JP30.6, R69.1, U28.3, U29.4, U30.2
GND10: C51.2, C52.2, C53.2, C54.2, C55.2, JP31.1, JP31.5, JP31.9, JP31.11, JP31.13, JP31.15, JP32.1, JP32.5, JP32.9, JP32.11, JP32.13, JP32.15, JP33.2, JP33.6, R76.1, U31.3, U32.4, U33.2
GND11: C56.2, C57.2, C58.2, C59.2, C60.2, JP34.1, JP34.5, JP34.9, JP34.11, JP34.13, JP34.15, JP35.1, JP35.5, JP35.9, JP35.11, JP35.13, JP35.15, JP36.2, JP36.6, R83.1, U34.3, U35.4, U36.2
GND12: C61.2, C62.2, C63.2, C64.2, C65.2, JP37.1, JP37.5, JP37.9, JP37.11, JP37.13, JP37.15, JP38.1, JP38.5, JP38.9, JP38.11, JP38.13, JP38.15, JP39.2, JP39.6, R90.1, U37.3, U38.4, U39.2
GND13: C66.2, C67.2, C68.2, C69.2, C70.2, JP40.1, JP40.5, JP40.9, JP40.11, JP40.13, JP40.15, JP41.1, JP41.5, JP41.9, JP41.11, JP41.13, JP41.15, JP42.2, JP42.6, R97.1, U40.3, U41.4, U42.2
GND14: C71.2, C72.2, C73.2, C74.2, C75.2, JP43.1, JP43.5, JP43.9, JP43.11, JP43.13, JP43.15, JP44.1, JP44.5, JP44.9, JP44.11, JP44.13, JP44.15, JP45.2, JP45.6, R104.1, U43.3, U44.4, U45.2
GND15: C76.2, C77.2, C78.2, C79.2, C80.2, JP46.1, JP46.5, JP46.9, JP46.11, JP46.13, JP46.15, JP47.1, JP47.5, JP47.9, JP47.11, JP47.13, JP47.15, JP48.2, JP48.6, R111.1, U46.3, U47.4, U48.2
GP1: JP4.48, JP5.48
GP2: JP4.42, JP5.42
GP3: JP4.34, JP5.34
GP4: JP4.32, JP5.32
GP5: JP4.30, JP5.30
GP6: JP4.28, JP5.28
GP7: JP4.26, JP5.26
GP8: JP4.25, JP5.25
GP9: JP4.24, JP5.24
GP10: JP7.48, JP8.48
GP11: JP7.42, JP8.42
GP12: JP7.34, JP8.34
GP12_PWM0: JP2.35, JP3.35
GP12_PWM1: JP4.35, JP5.35
GP12_PWM2: JP7.35, JP8.35
GP12_PWM3: JP10.35, JP11.35
GP12_PWM4: JP13.35, JP14.35
GP12_PWM5: JP16.35, JP17.35
GP12_PWM6: JP19.35, JP20.35
GP12_PWM7: JP22.35, JP23.35
GP12_PWM8: JP25.35, JP26.35
GP12_PWM9: JP28.35, JP29.35
GP12_PWM10: JP31.35, JP32.35
GP12_PWM11: JP34.35, JP35.35
GP12_PWM12: JP37.35, JP38.35
GP12_PWM13: JP40.35, JP41.35
GP12_PWM14: JP43.35, JP44.35
GP12_PWM15: JP46.35, JP47.35
GP13: JP7.32, JP8.32
GP13_PWM1: JP2.33, JP3.33
GP13_PWM2: JP4.33, JP5.33
GP13_PWM3: JP7.33, JP8.33
GP13_PWM4: JP10.33, JP11.33
GP13_PWM5: JP13.33, JP14.33
GP13_PWM6: JP16.33, JP17.33
GP13_PWM7: JP19.33, JP20.33
GP13_PWM8: JP22.33, JP23.33
GP13_PWM9: JP25.33, JP26.33
GP13_PWM10: JP28.33, JP29.33
GP13_PWM11: JP31.33, JP32.33
GP13_PWM12: JP34.33, JP35.33
GP13_PWM13: JP37.33, JP38.33
GP13_PWM14: JP40.33, JP41.33
GP13_PWM15: JP43.33, JP44.33
GP13_PWM16: JP46.33, JP47.33
GP14: JP2.48, JP3.48
GP15: JP2.42, JP3.42
GP16: JP7.30, JP8.30
GP17: JP7.28, JP8.28
GP18: JP7.26, JP8.26
GP19: JP7.25, JP8.25
GP19_I2C_1_SCL: JP2.41, JP3.41, SJ6.3
GP19_I2C_1_SCL1: JP4.41, JP5.41, SJ12.3
GP19_I2C_1_SCL2: JP7.41, JP8.41, SJ18.3
GP19_I2C_1_SCL3: JP10.41, JP11.41, SJ24.3
GP19_I2C_1_SCL4: JP13.41, JP14.41, SJ30.3
GP19_I2C_1_SCL5: JP16.41, JP17.41, SJ36.3
GP19_I2C_1_SCL6: JP19.41, JP20.41, SJ42.3
GP19_I2C_1_SCL7: JP22.41, JP23.41, SJ48.3
GP19_I2C_1_SCL8: JP25.41, JP26.41, SJ54.3
GP19_I2C_1_SCL9: JP28.41, JP29.41, SJ60.3
GP19_I2C_1_SCL10: JP31.41, JP32.41, SJ66.3
GP19_I2C_1_SCL11: JP34.41, JP35.41, SJ72.3
GP19_I2C_1_SCL12: JP37.41, JP38.41, SJ78.3
GP19_I2C_1_SCL13: JP40.41, JP41.41, SJ84.3
GP19_I2C_1_SCL14: JP43.41, JP44.41, SJ90.3
GP19_I2C_1_SCL15: JP46.41, JP47.41, SJ96.3
GP20: JP7.24, JP8.24
GP20_I2C_1_SDA: JP2.43, JP3.43, SJ5.3
GP20_I2C_1_SDA1: JP4.43, JP5.43, SJ11.3
GP20_I2C_1_SDA2: JP7.43, JP8.43, SJ17.3
GP20_I2C_1_SDA3: JP10.43, JP11.43, SJ23.3
GP20_I2C_1_SDA4: JP13.43, JP14.43, SJ29.3
GP20_I2C_1_SDA5: JP16.43, JP17.43, SJ35.3
GP20_I2C_1_SDA6: JP19.43, JP20.43, SJ41.3
GP20_I2C_1_SDA7: JP22.43, JP23.43, SJ47.3
GP20_I2C_1_SDA8: JP25.43, JP26.43, SJ53.3
GP20_I2C_1_SDA9: JP28.43, JP29.43, SJ59.3
GP20_I2C_1_SDA10: JP31.43, JP32.43, SJ65.3
GP20_I2C_1_SDA11: JP34.43, JP35.43, SJ71.3
GP20_I2C_1_SDA12: JP37.43, JP38.43, SJ77.3
GP20_I2C_1_SDA13: JP40.43, JP41.43, SJ83.3
GP20_I2C_1_SDA14: JP43.43, JP44.43, SJ89.3
GP20_I2C_1_SDA15: JP46.43, JP47.43, SJ95.3
GP21: JP10.48, JP11.48
GP22: JP10.42, JP11.42
GP23: JP10.34, JP11.34
GP24: JP10.32, JP11.32
GP25: JP10.30, JP11.30
GP26: JP10.28, JP11.28
GP27: JP10.26, JP11.26
GP27_I2C_6_SCL: JP2.45, JP3.45, SJ6.1
GP27_I2C_6_SCL1: JP4.45, JP5.45, SJ12.1
GP27_I2C_6_SCL2: JP7.45, JP8.45, SJ18.1
GP27_I2C_6_SCL3: JP10.45, JP11.45, SJ24.1
GP27_I2C_6_SCL4: JP13.45, JP14.45, SJ30.1
GP27_I2C_6_SCL5: JP16.45, JP17.45, SJ36.1
GP27_I2C_6_SCL6: JP19.45, JP20.45, SJ42.1
GP27_I2C_6_SCL7: JP22.45, JP23.45, SJ48.1
GP27_I2C_6_SCL8: JP25.45, JP26.45, SJ54.1
GP27_I2C_6_SCL9: JP28.45, JP29.45, SJ60.1
GP27_I2C_6_SCL10: JP31.45, JP32.45, SJ66.1
GP27_I2C_6_SCL11: JP34.45, JP35.45, SJ72.1
GP27_I2C_6_SCL12: JP37.45, JP38.45, SJ78.1
GP27_I2C_6_SCL13: JP40.45, JP41.45, SJ84.1
GP27_I2C_6_SCL14: JP43.45, JP44.45, SJ90.1
GP27_I2C_6_SCL15: JP46.45, JP47.45, SJ96.1
GP28: JP10.25, JP11.25
GP28_I2C_6_SDA: JP2.47, JP3.47, SJ5.1
GP28_I2C_6_SDA1: JP4.47, JP5.47, SJ11.1
GP28_I2C_6_SDA2: JP7.47, JP8.47, SJ17.1
GP28_I2C_6_SDA3: JP10.47, JP11.47, SJ23.1
GP28_I2C_6_SDA4: JP13.47, JP14.47, SJ29.1
GP28_I2C_6_SDA5: JP16.47, JP17.47, SJ35.1
GP28_I2C_6_SDA6: JP19.47, JP20.47, SJ41.1
GP28_I2C_6_SDA7: JP22.47, JP23.47, SJ47.1
GP28_I2C_6_SDA8: JP25.47, JP26.47, SJ53.1
GP28_I2C_6_SDA9: JP28.47, JP29.47, SJ59.1
GP28_I2C_6_SDA10: JP31.47, JP32.47, SJ65.1
GP28_I2C_6_SDA11: JP34.47, JP35.47, SJ71.1
GP28_I2C_6_SDA12: JP37.47, JP38.47, SJ77.1
GP28_I2C_6_SDA13: JP40.47, JP41.47, SJ83.1
GP28_I2C_6_SDA14: JP43.47, JP44.47, SJ89.1
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

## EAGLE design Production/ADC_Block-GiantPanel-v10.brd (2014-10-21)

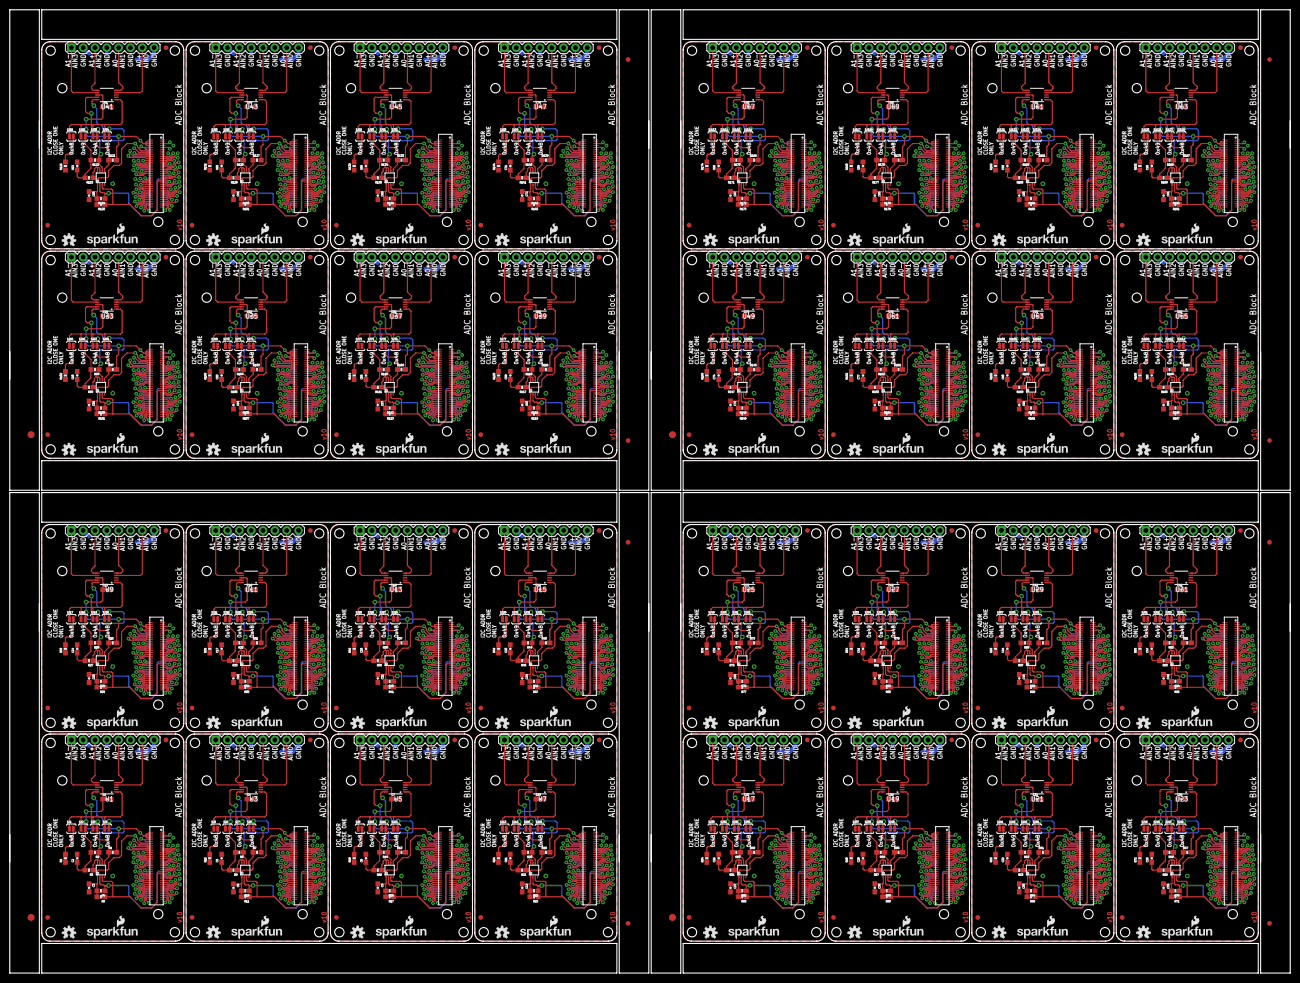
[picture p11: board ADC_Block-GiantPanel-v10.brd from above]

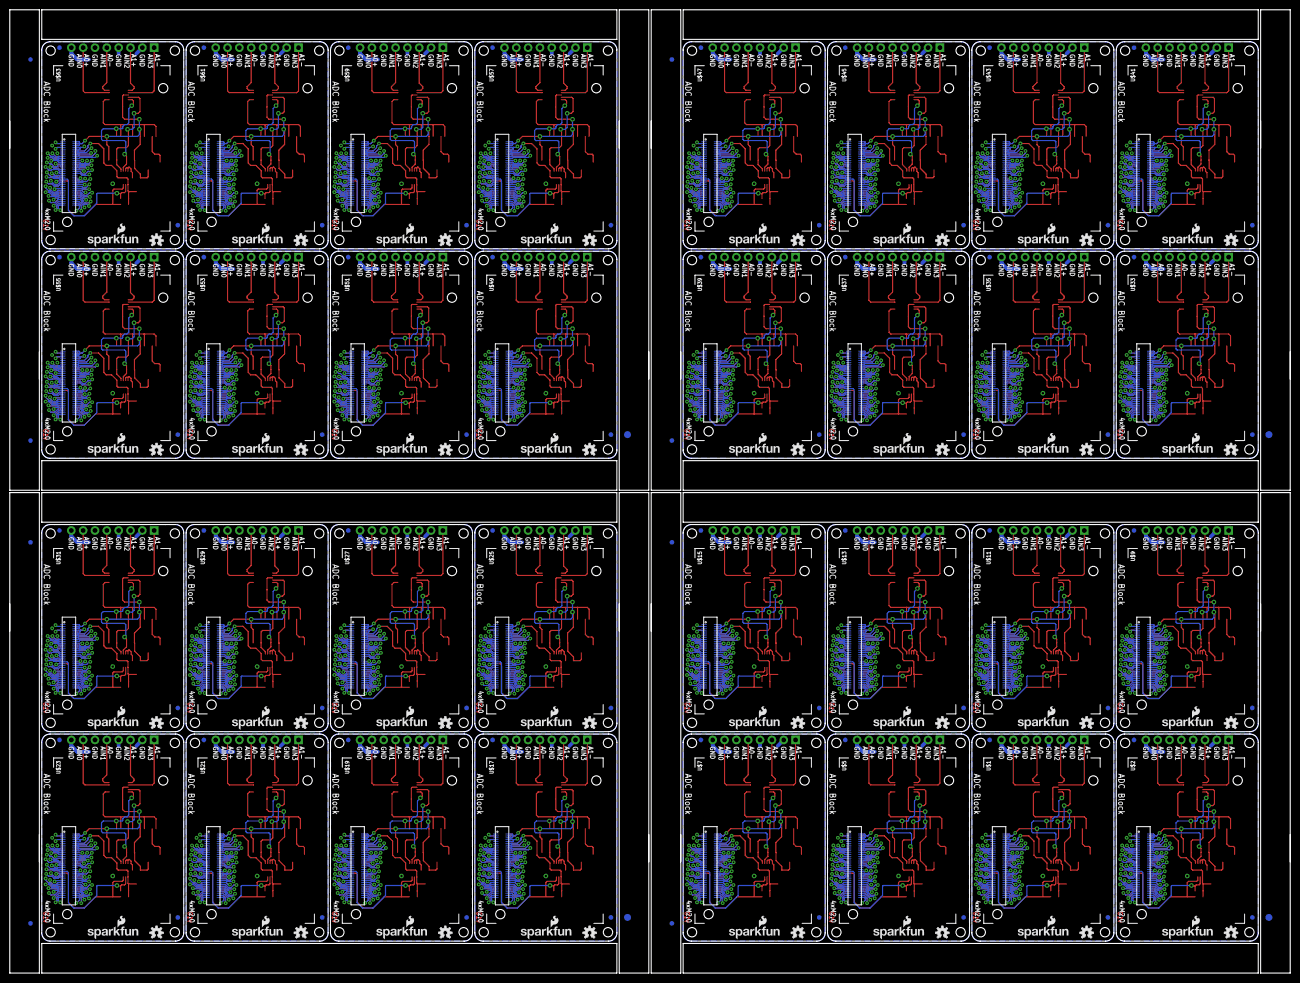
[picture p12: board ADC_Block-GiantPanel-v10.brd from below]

Board: 2 copper layers, 274.8 x 206.8 mm, 856 parts (204 on the bottom side), 2144 nets.

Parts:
C1, C2, C3, C4, C5, C6, C7, C8, C9, C10, C11, C12, C13, C14, C15, C16, C17, C18, C19, C20, C21, C22, C23, C24, C25, C26, C27, C28, C29, C30, C31, C32, C33, C34, C35, C36, C37, C38, C39, C40, C41, C42, C43, C44, C45, C46, C47, C48, C49, C50, C51, C52, C53, C54, C55, C56, C57, C58, C59, C60, C61, C62, C63, C64, C65, C66, C67, C68, C69, C70, C71, C72, C73, C74, C75, C76, C77, C78, C79, C80, C81, C82, C83, C84, C85, C86, C87, C88, C89, C90, C91, C92, C93, C94, C95, C96: 0.1uF; 0603-CAP
E$1, E$2, E$9, E$10, E$15, E$16, E$21, E$22: FIDUCIAL-1.5X3
E$3, E$4, E$5, E$6, E$7, E$8, E$11, E$12, E$13, E$14, E$17, E$18, E$19, E$20, E$23, E$24: FIDUCIAL-1X2
FID1, FID2, FID3, FID4, FID5, FID6, FID7, FID8, FID9, FID10, FID11, FID12, FID13, FID14, FID15, FID16, FID17, FID18, FID19, FID20, FID21, FID22, FID23, FID24, FID25, FID26, FID27, FID28, FID29, FID30, FID31, FID32, FID33, FID34, FID35, FID36, FID37, FID38, FID39, FID40, FID41, FID42, FID43, FID44, FID45, FID46, FID47, FID48, FID49, FID50, FID51, FID52, FID53, FID54, FID55, FID56, FID57, FID58, FID59, FID60, FID61, FID62, FID63, FID64, FID65, FID66, FID67, FID68, FID69, FID70, FID71, FID72, FID73, FID74, FID75, FID76, FID77, FID78, FID79, FID80, FID81, FID82, FID83, FID84, FID85, FID86, FID87, FID88, FID89, FID90, FID91, FID92, FID93, FID94, FID95, FID96, FID97, FID98, FID99, FID100, FID101, FID102, FID103, FID104, FID105, FID106, FID107, FID108, FID109, FID110, FID111, FID112, FID113, FID114, FID115, FID116, FID117, FID118, FID119, FID120, FID121, FID122, FID123, FID124, FID125, FID126, FID127, FID128: FIDUCIAL1X2; FIDUCIAL-1X2
JP1, JP2, JP3, JP4, JP5, JP6, JP7, JP8, JP9, JP10, JP11, JP12, JP13, JP14, JP15, JP16, JP17, JP18, JP19, JP20, JP21, JP22, JP23, JP24, JP25, JP26, JP27, JP28, JP29, JP30, JP31, JP32: 1X08
LOGO1, LOGO3, LOGO6, LOGO7, LOGO10, LOGO11, LOGO14, LOGO15, LOGO18, LOGO19, LOGO22, LOGO23, LOGO26, LOGO27, LOGO30, LOGO31, LOGO34, LOGO35, LOGO38, LOGO39, LOGO42, LOGO43, LOGO46, LOGO47, LOGO50, LOGO51, LOGO54, LOGO55, LOGO58, LOGO59, LOGO62, LOGO63, LOGO66, LOGO67, LOGO70, LOGO71, LOGO74, LOGO75, LOGO78, LOGO79, LOGO82, LOGO83, LOGO86, LOGO87, LOGO90, LOGO91, LOGO94, LOGO95, LOGO98, LOGO99, LOGO102, LOGO103, LOGO106, LOGO107, LOGO110, LOGO111, LOGO114, LOGO115, LOGO118, LOGO119, LOGO122, LOGO123, LOGO126, LOGO127: SFE_LOGO_NAME_FLAME.1_INCH; SFE_LOGO_NAME_FLAME_.1
LOGO2, LOGO4, LOGO5, LOGO8, LOGO9, LOGO12, LOGO13, LOGO16, LOGO17, LOGO20, LOGO21, LOGO24, LOGO25, LOGO28, LOGO29, LOGO32, LOGO33, LOGO36, LOGO37, LOGO40, LOGO41, LOGO44, LOGO45, LOGO48, LOGO49, LOGO52, LOGO53, LOGO56, LOGO57, LOGO60, LOGO61, LOGO64, LOGO65, LOGO68, LOGO69, LOGO72, LOGO73, LOGO76, LOGO77, LOGO80, LOGO81, LOGO84, LOGO85, LOGO88, LOGO89, LOGO92, LOGO93, LOGO96, LOGO97, LOGO100, LOGO101, LOGO104, LOGO105, LOGO108, LOGO109, LOGO112, LOGO113, LOGO116, LOGO117, LOGO120, LOGO121, LOGO124, LOGO125, LOGO128: OSHW-LOGOS; OSHW-LOGO-S
R1, R2, R7, R8, R13, R14, R19, R20, R25, R26, R31, R32, R37, R38, R43, R44, R49, R50, R55, R56, R61, R62, R67, R68, R73, R74, R79, R80, R85, R86, R91, R92, R97, R98, R103, R104, R109, R110, R115, R116, R121, R122, R127, R128, R133, R134, R139, R140, R145, R146, R151, R152, R157, R158, R163, R164, R169, R170, R175, R176, R181, R182, R187, R188: 10K; 0603-RES
R3, R9, R15, R21, R27, R33, R39, R45, R51, R57, R63, R69, R75, R81, R87, R93, R99, R105, R111, R117, R123, R129, R135, R141, R147, R153, R159, R165, R171, R177, R183, R189: 200k; 0603-RES
R4, R5, R10, R11, R16, R17, R22, R23, R28, R29, R34, R35, R40, R41, R46, R47, R52, R53, R58, R59, R64, R65, R70, R71, R76, R77, R82, R83, R88, R89, R94, R95, R100, R101, R106, R107, R112, R113, R118, R119, R124, R125, R130, R131, R136, R137, R142, R143, R148, R149, R154, R155, R160, R161, R166, R167, R172, R173, R178, R179, R184, R185, R190, R191: DNP; 0603-RES
R6, R12, R18, R24, R30, R36, R42, R48, R54, R60, R66, R72, R78, R84, R90, R96, R102, R108, R114, R120, R126, R132, R138, R144, R150, R156, R162, R168, R174, R180, R186, R192: 2.2k; 0603-RES
SJ1, SJ5, SJ9, SJ13, SJ17, SJ21, SJ25, SJ29, SJ33, SJ37, SJ41, SJ45, SJ49, SJ53, SJ57, SJ61, SJ65, SJ69, SJ73, SJ77, SJ81, SJ85, SJ89, SJ93, SJ97, SJ101, SJ105, SJ109, SJ113, SJ117, SJ121, SJ125: JUMPER-PAD-2-NC_BY_PASTE; PAD-JUMPER-2-NC_BY_PASTE_YES_SILK
SJ2, SJ3, SJ4, SJ6, SJ7, SJ8, SJ10, SJ11, SJ12, SJ14, SJ15, SJ16, SJ18, SJ19, SJ20, SJ22, SJ23, SJ24, SJ26, SJ27, SJ28, SJ30, SJ31, SJ32, SJ34, SJ35, SJ36, SJ38, SJ39, SJ40, SJ42, SJ43, SJ44, SJ46, SJ47, SJ48, SJ50, SJ51, SJ52, SJ54, SJ55, SJ56, SJ58, SJ59, SJ60, SJ62, SJ63, SJ64, SJ66, SJ67, SJ68, SJ70, SJ71, SJ72, SJ74, SJ75, SJ76, SJ78, SJ79, SJ80, SJ82, SJ83, SJ84, SJ86, SJ87, SJ88, SJ90, SJ91, SJ92, SJ94, SJ95, SJ96, SJ98, SJ99, SJ100, SJ102, SJ103, SJ104, SJ106, SJ107, SJ108, SJ110, SJ111, SJ112, SJ114, SJ115, SJ116, SJ118, SJ119, SJ120, SJ122, SJ123, SJ124, SJ126, SJ127, SJ128: JUMPER-PAD-2-NOYES_SILK; PAD-JUMPER-2-NO_YES_SILK
U1, U3, U5, U7, U9, U11, U13, U15, U17, U19, U21, U23, U25, U27, U29, U31, U33, U35, U37, U39, U41, U43, U45, U47, U49, U51, U53, U55, U57, U59, U61, U63: ADS1015; MSOP10
U2, U4, U6, U8, U10, U12, U14, U16, U18, U20, U22, U24, U26, U28, U30, U32, U34, U36, U38, U40, U42, U44, U46, U48, U50, U52, U54, U56, U58, U60, U62, U64: PCA9306; PCA9306DC-1:1
U$1, U$2, U$5, U$7, U$9, U$11, U$13, U$15, U$17, U$19, U$21, U$23, U$25, U$27, U$29, U$31, U$33, U$35, U$37, U$39, U$41, U$43, U$45, U$47, U$49, U$51, U$53, U$55, U$57, U$59, U$61, U$63: EDISON_CONNECTOR_FULLMOUNTING_HOLES; EDISON_DAUGHTER
U$3, U$4, U$6, U$8, U$10, U$12, U$14, U$16, U$18, U$20, U$22, U$24, U$26, U$28, U$30, U$32, U$34, U$36, U$38, U$40, U$42, U$44, U$46, U$48, U$50, U$52, U$54, U$56, U$58, U$60, U$62, U$64: EDISON_CONNECTOR_FULLHEADER; DF40C-70DP-0.4(51)

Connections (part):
1.8V: C3.1, R4.2, R5.2, U2.1, U$2.12, U$3.12
1.8V1: C6.1, R10.2, R11.2, U4.1, U$1.12, U$4.12
1.8V2: C9.1, R16.2, R17.2, U6.1, U$5.12, U$6.12
1.8V3: C12.1, R22.2, R23.2, U8.1, U$7.12, U$8.12
1.8V4: C15.1, R28.2, R29.2, U10.1, U$9.12, U$10.12
1.8V5: C18.1, R34.2, R35.2, U12.1, U$11.12, U$12.12
1.8V6: C21.1, R40.2, R41.2, U14.1, U$13.12, U$14.12
1.8V7: C24.1, R46.2, R47.2, U16.1, U$15.12, U$16.12
1.8V8: C27.1, R52.2, R53.2, U18.1, U$17.12, U$18.12
1.8V9: C30.1, R58.2, R59.2, U20.1, U$19.12, U$20.12
1.8V10: C33.1, R64.2, R65.2, U22.1, U$21.12, U$22.12
1.8V11: C36.1, R70.2, R71.2, U24.1, U$23.12, U$24.12
1.8V12: C39.1, R76.2, R77.2, U26.1, U$25.12, U$26.12
1.8V13: C42.1, R82.2, R83.2, U28.1, U$27.12, U$28.12
1.8V14: C45.1, R88.2, R89.2, U30.1, U$29.12, U$30.12
1.8V15: C48.1, R94.2, R95.2, U32.1, U$31.12, U$32.12
1.8V16: C51.1, R100.2, R101.2, U34.1, U$33.12, U$34.12
1.8V17: C54.1, R106.2, R107.2, U36.1, U$35.12, U$36.12
1.8V18: C57.1, R112.2, R113.2, U38.1, U$37.12, U$38.12
1.8V19: C60.1, R118.2, R119.2, U40.1, U$39.12, U$40.12
1.8V20: C63.1, R124.2, R125.2, U42.1, U$41.12, U$42.12
1.8V21: C66.1, R130.2, R131.2, U44.1, U$43.12, U$44.12
1.8V22: C69.1, R136.2, R137.2, U46.1, U$45.12, U$46.12
1.8V23: C72.1, R142.2, R143.2, U48.1, U$47.12, U$48.12
1.8V24: C75.1, R148.2, R149.2, U50.1, U$49.12, U$50.12
1.8V25: C78.1, R154.2, R155.2, U52.1, U$51.12, U$52.12
1.8V26: C81.1, R160.2, R161.2, U54.1, U$53.12, U$54.12
1.8V27: C84.1, R166.2, R167.2, U56.1, U$55.12, U$56.12
1.8V28: C87.1, R172.2, R173.2, U58.1, U$57.12, U$58.12
1.8V29: C90.1, R178.2, R179.2, U60.1, U$59.12, U$60.12
1.8V30: C93.1, R184.2, R185.2, U62.1, U$61.12, U$62.12
1.8V31: C96.1, R190.2, R191.2, U64.1, U$63.12, U$64.12
3.3V: U$2.8, U$2.10, U$3.8, U$3.10
3.3V1: U$1.8, U$1.10, U$4.8, U$4.10
3.3V2: U$5.8, U$5.10, U$6.8, U$6.10
3.3V3: U$7.8, U$7.10, U$8.8, U$8.10
3.3V4: U$9.8, U$9.10, U$10.8, U$10.10
3.3V5: U$11.8, U$11.10, U$12.8, U$12.10
3.3V6: U$13.8, U$13.10, U$14.8, U$14.10
3.3V7: U$15.8, U$15.10, U$16.8, U$16.10
3.3V8: U$17.8, U$17.10, U$18.8, U$18.10
3.3V9: U$19.8, U$19.10, U$20.8, U$20.10
3.3V10: U$21.8, U$21.10, U$22.8, U$22.10
3.3V11: U$23.8, U$23.10, U$24.8, U$24.10
3.3V12: U$25.8, U$25.10, U$26.8, U$26.10
3.3V13: U$27.8, U$27.10, U$28.8, U$28.10
3.3V14: U$29.8, U$29.10, U$30.8, U$30.10
3.3V15: U$31.8, U$31.10, U$32.8, U$32.10
3.3V16: U$33.8, U$33.10, U$34.8, U$34.10
3.3V17: U$35.8, U$35.10, U$36.8, U$36.10
3.3V18: U$37.8, U$37.10, U$38.8, U$38.10
3.3V19: U$39.8, U$39.10, U$40.8, U$40.10
3.3V20: U$41.8, U$41.10, U$42.8, U$42.10
3.3V21: U$43.8, U$43.10, U$44.8, U$44.10
3.3V22: U$45.8, U$45.10, U$46.8, U$46.10
3.3V23: U$47.8, U$47.10, U$48.8, U$48.10
3.3V24: U$49.8, U$49.10, U$50.8, U$50.10
3.3V25: U$51.8, U$51.10, U$52.8, U$52.10
3.3V26: U$53.8, U$53.10, U$54.8, U$54.10
3.3V27: U$55.8, U$55.10, U$56.8, U$56.10
3.3V28: U$57.8, U$57.10, U$58.8, U$58.10
3.3V29: U$59.8, U$59.10, U$60.8, U$60.10
3.3V30: U$61.8, U$61.10, U$62.8, U$62.10
3.3V31: U$63.8, U$63.10, U$64.8, U$64.10
A0+/AIN0: JP1.7, U1.4
A0+/AIN1: JP2.7, U3.4
A0+/AIN2: JP3.7, U5.4
A0+/AIN3: JP4.7, U7.4
A0+/AIN4: JP5.7, U9.4
A0+/AIN5: JP6.7, U11.4
A0+/AIN6: JP7.7, U13.4
A0+/AIN7: JP8.7, U15.4
A0+/AIN8: JP9.7, U17.4
A0+/AIN9: JP10.7, U19.4
A0+/AIN10: JP11.7, U21.4
A0+/AIN11: JP12.7, U23.4
A0+/AIN12: JP13.7, U25.4
A0+/AIN13: JP14.7, U27.4
A0+/AIN14: JP15.7, U29.4
A0+/AIN15: JP16.7, U31.4
A0+/AIN16: JP17.7, U33.4
A0+/AIN17: JP18.7, U35.4
A0+/AIN18: JP19.7, U37.4
A0+/AIN19: JP20.7, U39.4
A0+/AIN20: JP21.7, U41.4
A0+/AIN21: JP22.7, U43.4
A0+/AIN22: JP23.7, U45.4
A0+/AIN23: JP24.7, U47.4
A0+/AIN24: JP25.7, U49.4
A0+/AIN25: JP26.7, U51.4
A0+/AIN26: JP27.7, U53.4
A0+/AIN27: JP28.7, U55.4
A0+/AIN28: JP29.7, U57.4
A0+/AIN29: JP30.7, U59.4
A0+/AIN30: JP31.7, U61.4
A0+/AIN31: JP32.7, U63.4
A0-/AIN1: JP1.5, U1.5
A0-/AIN2: JP2.5, U3.5
A0-/AIN3: JP3.5, U5.5
A0-/AIN4: JP4.5, U7.5
A0-/AIN5: JP5.5, U9.5
A0-/AIN6: JP6.5, U11.5
A0-/AIN7: JP7.5, U13.5
A0-/AIN8: JP8.5, U15.5
A0-/AIN9: JP9.5, U17.5
A0-/AIN10: JP10.5, U19.5
A0-/AIN11: JP11.5, U21.5
A0-/AIN12: JP12.5, U23.5
A0-/AIN13: JP13.5, U25.5
A0-/AIN14: JP14.5, U27.5
A0-/AIN15: JP15.5, U29.5
A0-/AIN16: JP16.5, U31.5
A0-/AIN17: JP17.5, U33.5
A0-/AIN18: JP18.5, U35.5
A0-/AIN19: JP19.5, U37.5
A0-/AIN20: JP20.5, U39.5
A0-/AIN21: JP21.5, U41.5
A0-/AIN22: JP22.5, U43.5
A0-/AIN23: JP23.5, U45.5
A0-/AIN24: JP24.5, U47.5
A0-/AIN25: JP25.5, U49.5
A0-/AIN26: JP26.5, U51.5
A0-/AIN27: JP27.5, U53.5
A0-/AIN28: JP28.5, U55.5
A0-/AIN29: JP29.5, U57.5
A0-/AIN30: JP30.5, U59.5
A0-/AIN31: JP31.5, U61.5
A0-/AIN32: JP32.5, U63.5
A1+/AIN1: JP2.3, U3.6
A1+/AIN2: JP1.3, U1.6
A1+/AIN3: JP3.3, U5.6
A1+/AIN4: JP4.3, U7.6
A1+/AIN5: JP5.3, U9.6
A1+/AIN6: JP6.3, U11.6
A1+/AIN7: JP7.3, U13.6
A1+/AIN8: JP8.3, U15.6
A1+/AIN9: JP9.3, U17.6
A1+/AIN10: JP10.3, U19.6
A1+/AIN11: JP11.3, U21.6
A1+/AIN12: JP12.3, U23.6
A1+/AIN13: JP13.3, U25.6
A1+/AIN14: JP14.3, U27.6
A1+/AIN15: JP15.3, U29.6
A1+/AIN16: JP16.3, U31.6
A1+/AIN17: JP17.3, U33.6
A1+/AIN18: JP18.3, U35.6
A1+/AIN19: JP19.3, U37.6
A1+/AIN20: JP20.3, U39.6
A1+/AIN21: JP21.3, U41.6
A1+/AIN22: JP22.3, U43.6
A1+/AIN23: JP23.3, U45.6
A1+/AIN24: JP24.3, U47.6
A1+/AIN25: JP25.3, U49.6
A1+/AIN26: JP26.3, U51.6
A1+/AIN27: JP27.3, U53.6
A1+/AIN28: JP28.3, U55.6
A1+/AIN29: JP29.3, U57.6
A1+/AIN30: JP30.3, U59.6
A1+/AIN31: JP31.3, U61.6
A1+/AIN32: JP32.3, U63.6
A1-/AIN1: JP2.1, U3.7
A1-/AIN2: JP3.1, U5.7
A1-/AIN3: JP1.1, U1.7
A1-/AIN4: JP4.1, U7.7
A1-/AIN5: JP5.1, U9.7
A1-/AIN6: JP6.1, U11.7
A1-/AIN7: JP7.1, U13.7
A1-/AIN8: JP8.1, U15.7
A1-/AIN9: JP9.1, U17.7
A1-/AIN10: JP10.1, U19.7
A1-/AIN11: JP11.1, U21.7
A1-/AIN12: JP12.1, U23.7
A1-/AIN13: JP13.1, U25.7
A1-/AIN14: JP14.1, U27.7
A1-/AIN15: JP15.1, U29.7
A1-/AIN16: JP16.1, U31.7
A1-/AIN17: JP17.1, U33.7
A1-/AIN18: JP18.1, U35.7
A1-/AIN19: JP19.1, U37.7
A1-/AIN20: JP20.1, U39.7
A1-/AIN21: JP21.1, U41.7
A1-/AIN22: JP22.1, U43.7
A1-/AIN23: JP23.1, U45.7
A1-/AIN24: JP24.1, U47.7
A1-/AIN25: JP25.1, U49.7
A1-/AIN26: JP26.1, U51.7
A1-/AIN27: JP27.1, U53.7
A1-/AIN28: JP28.1, U55.7
A1-/AIN29: JP29.1, U57.7
A1-/AIN30: JP30.1, U59.7
A1-/AIN31: JP31.1, U61.7
A1-/AIN32: JP32.1, U63.7
ADDR: SJ1.1, SJ2.1, SJ3.1, SJ4.1, U1.1
ADDR1: SJ5.1, SJ6.1, SJ7.1, SJ8.1, U3.1
ADDR2: SJ9.1, SJ10.1, SJ11.1, SJ12.1, U5.1
ADDR3: SJ13.1, SJ14.1, SJ15.1, SJ16.1, U7.1
ADDR4: SJ17.1, SJ18.1, SJ19.1, SJ20.1, U9.1
ADDR5: SJ21.1, SJ22.1, SJ23.1, SJ24.1, U11.1
ADDR6: SJ25.1, SJ26.1, SJ27.1, SJ28.1, U13.1
ADDR7: SJ29.1, SJ30.1, SJ31.1, SJ32.1, U15.1
ADDR8: SJ33.1, SJ34.1, SJ35.1, SJ36.1, U17.1
ADDR9: SJ37.1, SJ38.1, SJ39.1, SJ40.1, U19.1
ADDR10: SJ41.1, SJ42.1, SJ43.1, SJ44.1, U21.1
ADDR11: SJ45.1, SJ46.1, SJ47.1, SJ48.1, U23.1
ADDR12: SJ49.1, SJ50.1, SJ51.1, SJ52.1, U25.1
ADDR13: SJ53.1, SJ54.1, SJ55.1, SJ56.1, U27.1
ADDR14: SJ57.1, SJ58.1, SJ59.1, SJ60.1, U29.1
ADDR15: SJ61.1, SJ62.1, SJ63.1, SJ64.1, U31.1
ADDR16: SJ65.1, SJ66.1, SJ67.1, SJ68.1, U33.1
ADDR17: SJ69.1, SJ70.1, SJ71.1, SJ72.1, U35.1
ADDR18: SJ73.1, SJ74.1, SJ75.1, SJ76.1, U37.1
ADDR19: SJ77.1, SJ78.1, SJ79.1, SJ80.1, U39.1
ADDR20: SJ81.1, SJ82.1, SJ83.1, SJ84.1, U41.1
ADDR21: SJ85.1, SJ86.1, SJ87.1, SJ88.1, U43.1
ADDR22: SJ89.1, SJ90.1, SJ91.1, SJ92.1, U45.1
ADDR23: SJ93.1, SJ94.1, SJ95.1, SJ96.1, U47.1
ADDR24: SJ97.1, SJ98.1, SJ99.1, SJ100.1, U49.1
ADDR25: SJ101.1, SJ102.1, SJ103.1, SJ104.1, U51.1
ADDR26: SJ105.1, SJ106.1, SJ107.1, SJ108.1, U53.1
ADDR27: SJ109.1, SJ110.1, SJ111.1, SJ112.1, U55.1
ADDR28: SJ113.1, SJ114.1, SJ115.1, SJ116.1, U57.1
ADDR29: SJ117.1, SJ118.1, SJ119.1, SJ120.1, U59.1
ADDR30: SJ121.1, SJ122.1, SJ123.1, SJ124.1, U61.1
ADDR31: SJ125.1, SJ126.1, SJ127.1, SJ128.1, U63.1
DCIN: U$2.14, U$3.14
DCIN1: U$1.14, U$4.14
DCIN2: U$5.14, U$6.14
DCIN3: U$7.14, U$8.14
DCIN4: U$9.14, U$10.14
DCIN5: U$11.14, U$12.14
DCIN6: U$13.14, U$14.14
DCIN7: U$15.14, U$16.14
DCIN8: U$17.14, U$18.14
DCIN9: U$19.14, U$20.14
DCIN10: U$21.14, U$22.14
DCIN11: U$23.14, U$24.14
DCIN12: U$25.14, U$26.14
DCIN13: U$27.14, U$28.14
DCIN14: U$29.14, U$30.14
DCIN15: U$31.14, U$32.14
DCIN16: U$33.14, U$34.14
DCIN17: U$35.14, U$36.14
DCIN18: U$37.14, U$38.14
DCIN19: U$39.14, U$40.14
DCIN20: U$41.14, U$42.14
DCIN21: U$43.14, U$44.14
DCIN22: U$45.14, U$46.14
DCIN23: U$47.14, U$48.14
DCIN24: U$49.14, U$50.14
DCIN25: U$51.14, U$52.14
DCIN26: U$53.14, U$54.14
DCIN27: U$55.14, U$56.14
DCIN28: U$57.14, U$58.14
DCIN29: U$59.14, U$60.14
DCIN30: U$61.14, U$62.14
DCIN31: U$63.14, U$64.14
FAULT: U$2.19, U$3.19
FAULT1: U$1.19, U$4.19
FAULT2: U$5.19, U$6.19
FAULT3: U$7.19, U$8.19
FAULT4: U$9.19, U$10.19
FAULT5: U$11.19, U$12.19
FAULT6: U$13.19, U$14.19
FAULT7: U$15.19, U$16.19
FAULT8: U$17.19, U$18.19
FAULT9: U$19.19, U$20.19
FAULT10: U$21.19, U$22.19
FAULT11: U$23.19, U$24.19
FAULT12: U$25.19, U$26.19
FAULT13: U$27.19, U$28.19
FAULT14: U$29.19, U$30.19
FAULT15: U$31.19, U$32.19
FAULT16: U$33.19, U$34.19
FAULT17: U$35.19, U$36.19
FAULT18: U$37.19, U$38.19
FAULT19: U$39.19, U$40.19
FAULT20: U$41.19, U$42.19
FAULT21: U$43.19, U$44.19
FAULT22: U$45.19, U$46.19
FAULT23: U$47.19, U$48.19
FAULT24: U$49.19, U$50.19
FAULT25: U$51.19, U$52.19
FAULT26: U$53.19, U$54.19
FAULT27: U$55.19, U$56.19
FAULT28: U$57.19, U$58.19
FAULT29: U$59.19, U$60.19
FAULT30: U$61.19, U$62.19
FAULT31: U$63.19, U$64.19
FW_RCVR: U$2.69, U$3.69
FW_RCVR1: U$1.69, U$4.69
FW_RCVR2: U$5.69, U$6.69
FW_RCVR3: U$7.69, U$8.69
FW_RCVR4: U$9.69, U$10.69
FW_RCVR5: U$11.69, U$12.69
FW_RCVR6: U$13.69, U$14.69
FW_RCVR7: U$15.69, U$16.69
FW_RCVR8: U$17.69, U$18.69
FW_RCVR9: U$19.69, U$20.69
FW_RCVR10: U$21.69, U$22.69
FW_RCVR11: U$23.69, U$24.69
FW_RCVR12: U$25.69, U$26.69
FW_RCVR13: U$27.69, U$28.69
FW_RCVR14: U$29.69, U$30.69
FW_RCVR15: U$31.69, U$32.69
FW_RCVR16: U$33.69, U$34.69
FW_RCVR17: U$35.69, U$36.69
FW_RCVR18: U$37.69, U$38.69
FW_RCVR19: U$39.69, U$40.69
FW_RCVR20: U$41.69, U$42.69
FW_RCVR21: U$43.69, U$44.69
FW_RCVR22: U$45.69, U$46.69
FW_RCVR23: U$47.69, U$48.69
FW_RCVR24: U$49.69, U$50.69
FW_RCVR25: U$51.69, U$52.69
FW_RCVR26: U$53.69, U$54.69
FW_RCVR27: U$55.69, U$56.69
FW_RCVR28: U$57.69, U$58.69
FW_RCVR29: U$59.69, U$60.69
FW_RCVR30: U$61.69, U$62.69
FW_RCVR31: U$63.69, U$64.69
GND: C1.2, C2.2, C3.2, JP1.2, JP1.4, JP1.6, JP1.8, R6.1, U1.3, U2.4, U$2.1, U$2.5, U$2.9, U$2.11, U$2.13, U$2.15, U$3.1, U$3.5, U$3.9, U$3.11, U$3.13, U$3.15
GND1: C4.2, C5.2, C6.2, JP2.2, JP2.4, JP2.6, JP2.8, R12.1, U3.3, U4.4, U$1.1, U$1.5, U$1.9, U$1.11, U$1.13, U$1.15, U$4.1, U$4.5, U$4.9, U$4.11, U$4.13, U$4.15
GND2: C7.2, C8.2, C9.2, JP3.2, JP3.4, JP3.6, JP3.8, R18.1, U5.3, U6.4, U$5.1, U$5.5, U$5.9, U$5.11, U$5.13, U$5.15, U$6.1, U$6.5, U$6.9, U$6.11, U$6.13, U$6.15
GND3: C10.2, C11.2, C12.2, JP4.2, JP4.4, JP4.6, JP4.8, R24.1, U7.3, U8.4, U$7.1, U$7.5, U$7.9, U$7.11, U$7.13, U$7.15, U$8.1, U$8.5, U$8.9, U$8.11, U$8.13, U$8.15
GND4: C13.2, C14.2, C15.2, JP5.2, JP5.4, JP5.6, JP5.8, R30.1, U9.3, U10.4, U$9.1, U$9.5, U$9.9, U$9.11, U$9.13, U$9.15, U$10.1, U$10.5, U$10.9, U$10.11, U$10.13, U$10.15
GND5: C16.2, C17.2, C18.2, JP6.2, JP6.4, JP6.6, JP6.8, R36.1, U11.3, U12.4, U$11.1, U$11.5, U$11.9, U$11.11, U$11.13, U$11.15, U$12.1, U$12.5, U$12.9, U$12.11, U$12.13, U$12.15
GND6: C19.2, C20.2, C21.2, JP7.2, JP7.4, JP7.6, JP7.8, R42.1, U13.3, U14.4, U$13.1, U$13.5, U$13.9, U$13.11, U$13.13, U$13.15, U$14.1, U$14.5, U$14.9, U$14.11, U$14.13, U$14.15
GND7: C22.2, C23.2, C24.2, JP8.2, JP8.4, JP8.6, JP8.8, R48.1, U15.3, U16.4, U$15.1, U$15.5, U$15.9, U$15.11, U$15.13, U$15.15, U$16.1, U$16.5, U$16.9, U$16.11, U$16.13, U$16.15
GND8: C25.2, C26.2, C27.2, JP9.2, JP9.4, JP9.6, JP9.8, R54.1, U17.3, U18.4, U$17.1, U$17.5, U$17.9, U$17.11, U$17.13, U$17.15, U$18.1, U$18.5, U$18.9, U$18.11, U$18.13, U$18.15
GND9: C28.2, C29.2, C30.2, JP10.2, JP10.4, JP10.6, JP10.8, R60.1, U19.3, U20.4, U$19.1, U$19.5, U$19.9, U$19.11, U$19.13, U$19.15, U$20.1, U$20.5, U$20.9, U$20.11, U$20.13, U$20.15
GND10: C31.2, C32.2, C33.2, JP11.2, JP11.4, JP11.6, JP11.8, R66.1, U21.3, U22.4, U$21.1, U$21.5, U$21.9, U$21.11, U$21.13, U$21.15, U$22.1, U$22.5, U$22.9, U$22.11, U$22.13, U$22.15
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

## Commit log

2014-08-06 Board ready for review
    [adc_board.brd, adc_board.sch]
2014-08-06 Add version info
    [adc_board.brd, adc_board.sch]
2014-08-06 Updated to new edison.lbr
    [adc_board.brd, adc_board.sch]
2014-08-08 Incorporate review feedback
    [adc_board.brd, adc_board.sch]
2014-08-11 Add fids
    [adc_board.brd, adc_board.sch]
2014-08-12 Fix fids, remove weird name
    [adc_board.brd, adc_board.sch]
2014-09-24 Added DCIN pin Renamed boards and moved name around clenaed up copper pours clenaed up dimensions and units.
    [ADC_Block.brd, ADC_Block.sch]
2014-10-16 Chg pullups to 10k, update gnd and pwr traces, rev to 10
    [ADC_Block.brd, ADC_Block.sch]
2014-10-17 Rev to 10, fix pwr, gnd, txt
    [ADC_Block.brd, ADC_Block.sch]
2014-10-17 removed stray Bplace from Package
    [ADC_Block.brd, ADC_Block.sch]
2014-10-17 Ready for reds.
    Changed some silk to make headers more clear.
    No known to-do list.
    [ADC_Block.brd]
2014-10-21 created v10 panels
    [ADC_Block-GiantPanel-v10.brd, ADC_Block-Panel-v10.brd]
2015-01-08 made modifications to add a 3.3v reference voltage and power supply to measure potentiometers from. This will allow the block to be used in a stand alone mode.
    [ADC_Block.brd, ADC_Block.sch]
2015-03-16 updated rev number
    [ADC_Block.brd, ADC_Block.sch]
2015-03-16 added ground vias and removed right angle trace
    [ADC_Block.brd]
2015-03-23 corrected issues in github
    [ADC_Block.brd, ADC_Block.sch]
2015-04-01 Updating README and directory file name
    [ADC_Block-GiantPanel-v10.brd, ADC_Block-Panel-v10.brd]
2015-04-09 changing pour layers
    [ADC_Block.brd]
2015-04-09 copper restrict changes
    [ADC_Block.brd]
2015-04-13 added Bus selection to board
    [ADC_Block.brd, ADC_Block.sch]
2015-04-13 added note to SCH
    [ADC_Block.sch]
2015-04-28 made changes from github issues
    [ADC_Block.brd]
2015-06-02 Chg silk for diff chl info
    [ADC_Block.brd, ADC_Block.sch]
2015-06-10 Finalized silk for both side for diff chl info
    [ADC_Block.brd]
2015-06-25 moved differential pair chart and added separation lines
    [ADC_Block.brd]
2015-06-25 replaces output capacitor on the 3.3v regulator with 2.2uF
    [ADC_Block.brd, ADC_Block.sch]
2015-07-20 fixed thermal issue preventing gnd pour to connect with pads
    [ADC_Block.brd, ADC_Block.sch]
2015-07-20 updated part values
    [ADC_Block.sch]
2015-08-05 created panel v20
    [ADC_Block-GiantPanel-v10.brd, ADC_Block-Panel-v10.brd, ADC_Block_Giant_Panel_v20.brd]
2015-10-01 Updating README, adding license file
    [ADC_Block-GiantPanel-v10.brd, ADC_Block-Panel-v10.brd]
2015-10-27 Added resistor to output cap on LDO. Changed header to locking male header.
    [ADC_Block.brd, ADC_Block.sch]
2015-10-28 Cleaned up traces. Moved revision notes on schematic.
    [ADC_Block.brd, ADC_Block.sch]
2015-12-03 Changed R4 and R5 to DNP, which is how they were in v21.
    [ADC_Block.brd, ADC_Block.sch]
2015-12-11 Moved pin 1 markers to outside packages on IC and Hirose connectors.
    [ADC_Block.brd, ADC_Block.sch]
2015-12-11 Changed solder jumper to make I2C_6 default
    [ADC_Block.brd, ADC_Block.sch]
2015-12-11 Added notes about PCB thickness and DRC rules
    [ADC_Block.brd]
2015-12-14 Changed I2C back to bus 1 for default
    [ADC_Block.brd, ADC_Block.sch]
2015-12-14 created panel v21
    [ADC_Block_Panel_v21.brd]

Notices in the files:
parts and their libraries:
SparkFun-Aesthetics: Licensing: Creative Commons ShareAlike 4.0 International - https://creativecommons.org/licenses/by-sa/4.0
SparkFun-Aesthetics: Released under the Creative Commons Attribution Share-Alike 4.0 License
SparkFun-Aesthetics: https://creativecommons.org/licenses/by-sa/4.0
